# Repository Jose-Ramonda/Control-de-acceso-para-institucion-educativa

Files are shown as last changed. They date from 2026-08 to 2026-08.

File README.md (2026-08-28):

# Control de acceso para institución educativa
Repositorio del proyecto final de carrera "Control de acceso para institución educativa" de la Facultad de Ciencias Exactas Ingeniería y Agrimensura de la Universidad Nacional de Rosario. Desarrollado por José Ramonda y dirigido por Prof. Ing. Daniel Marquez.
La explicación detallada del desarrollo se encuentra en el informe subido.

El directorio "Servidor" contiene los archivos de implementación del servidor para funcionar en cualquier dispositivo con Linux. Para utilizar instalar Mosquitto y Node-Red, clonar el repositorio, copiar el backup de Node-Red (configurar seguridad de acceso). Luego crear entorno virtual y configurar los archivos "main.py" y "bot/bot.py" como servicios.
Configuraciones importantes: 
-Añadir archivo de texto plano con token de API de Telegram
-Configurar en "bot/botconfig.py" la ruta del archivo
-Para implementación en Raspberry Pi, activar uso de UART y cambiar la dirección del puerto serie. 
-Establezca sus propias credenciales de acceso al bot, así como su propio padrón de accesos.

El directorio "terminales" incluye los proyectos de ESP-IDF donde se programó el firmware de las placas de desarrollo ESP32 Devkit y ESP32-CAM, y los arcivos de Kicad de diseño de una PCB para el prototipado.

Para consultas comunicarse a josenramonda@gmail.com

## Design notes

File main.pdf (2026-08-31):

## Universidad Nacional de Rosario

## Facultad de Ciencias Exactas, Ingeniería y Agrimensura

## Escuela de Ingeniería Electrónica

## Proyecto II

## Control de Acceso para institución

## educativa

## Año: 2026

### Autor: Ramonda, José

Legajo: R-4423/7

Director:

### Prof. Ing. Daniel Marquez

### Rosario, 31 de agosto de 2026

## 1. Resumen

En el presente documento se desarrolla el proyecto de finalización de carrera “Control de acceso para institución educativa”, el cual implementa un sistema de gestión y registro de ingresos. El sistema permite el acceso regular del personal autorizado mediante credenciales basadas en tecnología NFC (Near Field Communication) y la validación remota de visitantes externos por parte de un operador humano, utilizando el reconocimiento visual a partir de fotografías recibidas en un dispositivo móvil.

## Índice

1. Resumen | 2
2. Problemática | 5
3. Funcionamiento del sistema | 6
4. Alcance del proyecto | 9
5. Terminales | 10
6. Servidor | 32

6.4. Selección del hardware del servidor y migración a Linux embebido . . 42
7. Seguridad | 43
8. Ensayos | 49
8.3.1. Medición de tiempo de apertura por acceso autorizado . . . . 50
9. Conclusiones | 54
10.Trabajo futuro | 55
11.Referencias | 56
12.Anexos | 57
12.2.3. Ensayo a 115200 baudios con retardo entre encuestas de 10 ms 67

## 2. Problemática

La problemática fue planteada por la dirección de la E.E.S.O. N.º 214 “Mariano Moreno”, ubicada en Santa Isabel, provincia de Santa Fe. Asumiendo el rol de cliente, la institución expuso la siguiente situación respecto al control de acceso y la seguridad: las puertas del establecimiento no pueden permanecer abiertas de forma ininterrumpida; sin embargo, resulta inviable destinar personal exclusivo para habilitar el ingreso de individuos autorizados o visitantes externos (como tutores legales) fuera de los horarios de entrada masiva. Frecuentemente, las oficinas de dirección se encuentran vacías y el personal asistente se halla realizando tareas de mantenimiento en zonas donde no es posible percibir el timbre sonoro. A esto se suma la ineficiencia que supone el desplazamiento físico con llaves mecánicas hacia cualquiera de los múltiples puntos de acceso cada vez que se requiere habilitar una entrada.
Para dar respuesta a estas necesidades, se requiere el diseño de un sistema que: Permita el acceso autónomo del personal de la escuela (docente y no docente), guardando los registros correspondientes para auditoría.
Permita que un operador autorizado habilite el acceso a un visitante externo de forma remota desde un dispositivo móvil, validando la identidad del individuo mediante una captura fotográfica.

Esta modalidad también permite gestionar los ingresos durante el horario de clases, momento en el cual las puertas deben permanecer bloqueadas, a diferencia de los horarios de entrada y salida regular. Por fuera del horario de actividades escolares, el edificio se asegura convencionalmente mediante cerraduras mecánicas.
Un condicionante crítico para el diseño es el factor económico, dado que los costos de implementación deben ajustarse estrictamente a las limitaciones presupuestarias de una escuela pública.
Respecto a las características arquitectónicas, el edificio ocupa una manzana completa y el sistema debe gestionar tres puntos físicos de acceso: la entrada de alumnos (patio principal), la entrada de docentes y el portón del bicicletero, el cual comunica con el patio exterior destinado a las clases de educación física. Las distancias de cableado desde cada una de estas puertas hasta la oficina designada para alojar el servidor central son de 7,5 m, 3 m y 40 m, respectivamente.

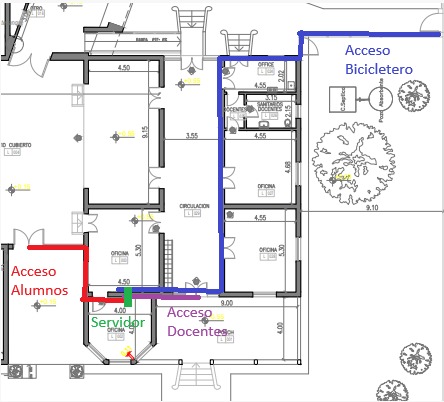
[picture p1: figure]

Figura 1: Plano de la institución resaltando los accesos y ubicación del servidor

## 3. Funcionamiento del sistema

El sistema funciona en un horario determinado correspondiente al horario escolar. Por fuera de ese horario el sistema permanece inactivo y las puertas cerradas con llave. Durante los horarios de ingreso, las puertas permanecen abiertas para evitar “cuellos de botella” por parte de los alumnos, pero una vez iniciado el periodo de clases, las puertas permanecen cerradas. Del lado de afuera se debe instalar un manijón que no permita que se accione el resbalón, ya que este lo acciona un destrabador eléctrico comandado por el sistema. Del lado interior se coloca un picaporte, que permita el egreso en todo momento por motivos de seguridad ante una posible evacuación. En casos de fallas del suministro energético, cuando el destrabador no pueda accionarse, basta con accionar el resbalón desde dentro con el picaporte o desde fuera con la llave.

En caso de que un visitante externo, por ejemplo el tutor de un alumno, visite la escuela, al tocar el pulsador del timbre de alguna de las puertas se le toma una fotografía que llega al dispositivo movil de la persona a cargo, quien decide si comandar o no una apertura. El timbre sonoro debe seguir funcionando normalmente.

El personal de la institución contará con credenciales de acceso en formato de tags NFC, con los que podrán acceder sin mediación humana. El sistema deberá llevar registro de cada acceso por cualquiera de los dos medios mencionados.

### 3.1. Arquitectura del sistema

El sistema se compone de un nodo servidor implementado en una single board computer (SBC) comunicado con tres nodos llamados terminales, construidos en base a microcontroladores, ubicados físicamente en cada punto de acceso. El servidor gestiona las comunicaciones, los registros, los permisos de acceso y por supuesto, comanda a los terminales. Los terminales son los que comandan, bajo demanda del servidor, el desbloqueo de las puertas mediante sendos relés que accionan los destrabadores eléctricos. También controlan las cámaras que toman las fotografías del exterior y los sensores NFC para transmitir la información de estos al servidor. Existen dos canales de comunicación entre nodos:

Comunicación serial cableada mediante protocolo RS-485 para el flujo de comandos, configuraciones y eventos, ya que es un estandar robusto utilizado en la industria, de velocidades considerables y pensado para grandes distancias.

Conexión a la red local, en el caso de los terminales via WiFi, mientras que el servidor puede conectarse via wifi o mediante cable de red si fuera posible, para transmitir las fotografías tomadas, dado que su transmición no es crítica en tiempo y que una fotografía se corresponde a un volumen de datos mayor que puede congestionar el canal principal.

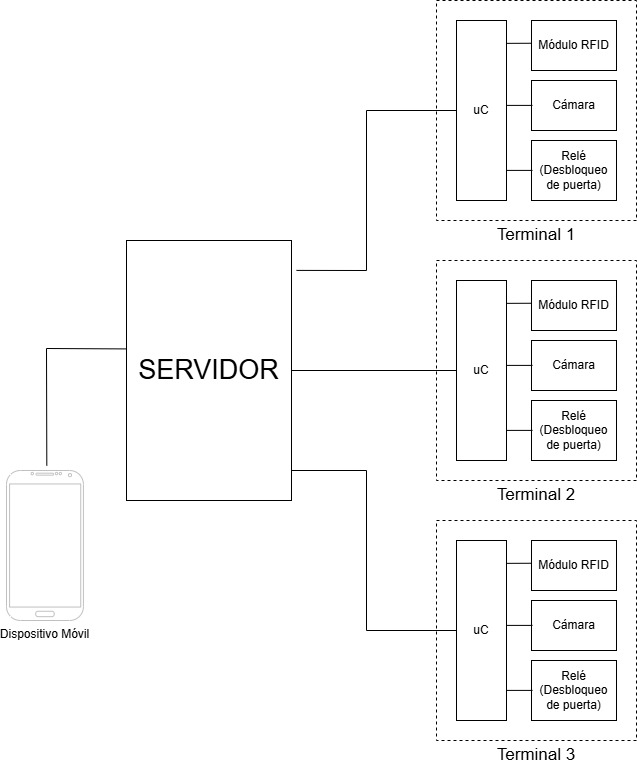
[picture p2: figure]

Figura 2: Diagrama de bloques del sistema

### 3.2. Actores del sistema

El sistema reconoce tres tipos de actores humanos.
Los accesos autorizados son aquellos que cuenten con una credencial o “tag” nfc autorizado y puedan acceder al presentarlo frente al lector. El lector debe validar la identidad del tag mediante contraseña, recolectar la identificación y contador de accesos y enviarla al servidor, para que este contraste con la lista de tags permitidos y responda con la orden de apertura o de no apertura. El Funcionamiento de la lectura y validación se detalla en la sección 5.2.6. El sistema debe tener capacidad para al menos 50 accesos autorizados, ya que representan al personal de la escuela (docente y no-docente) compuesto de alrededor de 30 personas. Se deja capacidad de reserva para cambios, incorporaciones y repuestos.
Los visitantes externos son aquellas personas que no tienen autorización de ingresar fuera del horario de apertura. Estos, al pulsar el boton del timbre, son fotografiados por la cámara del terminal. La fotografía es enviada hacia el servidor, el cual lo envía hacia el dispositivo móvil donde un usuario final valida la identidad del visitante y concede o no el acceso.
Los usuarios finales son aquellos con acceso a la interfaz de usuario de los dispositivos móviles. Para acceder a la interfaz estos deben iniciar sesión con credenciales (usuario y contraseña). Según las credenciales pueden tener distintos roles. El más básico es el de usuario, cuya sesión permanece abierta en el dispositivo a menos que se cierre explícitamente o que se reabra en otro dispositivo. Este rol permite solo acciones básicas tales como comandar aperturas o solicitar fotografías. Este rol está dedicado al personal no docente, directivo o administrativo. El sistema admite hasta 6 usuarios con este rol. Ciertos usuarios puden, mediante credenciales extra, abrir una sesión temporal de administrador, este rol permite configurar credenciales y añadir autorizaciones de accesos. Estas credenciales pertenecen solo a los directivos. Finalmente, queda un rol de desarrollador al cual se accede con otras credenciales mediante un comando no disponible en el menú. Este rol no está pensado para el personal de la institución sino a quienes esten a cargo de la instalación y el mantenimiento del sistema, y permite realizar acciones simples sobre este sin la necesidad de acceder al servidor mediante SSH.

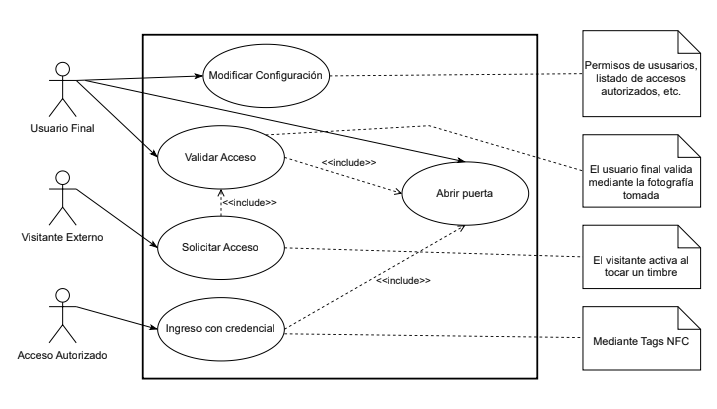
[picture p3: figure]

Figura 3: Diagrama UML de casos de uso.

### 3.3. Interfaces de usuario

La interfaz principal para los usuarios finales funciona a travéz de un bot de la aplicación de mensajería instantanea “Telegram”, ya que la API es amigable con los desarrolladores y permite utilizar menúes y comandos de forma sencilla, además de que soluciona la conectividad con el exterior, sin tener que configurar manualmente puertos ni firewalls. Otra ventaja respecto a desarrollar una aplicación nativa es que no hay que hacer un desarrollo distinto para cada sistema operativo móvil.
El bot es en esencia un programa que se ejecuta permanentemente en el servidor y mediante llamadas a API recibe, procesa y envía mensajes al chat del bot.
Los registros históricos de accesos se dan en formatos legibles y se cargan diariamente a google drive mediante su API. Esto permite un fácil acceso a los datos y un ahorro de memoria del servidor al almacenar en la nube.

### 3.4. Requerimientos del sistema

Los requisitos temporales del sistema no son estrictos al punto de requerir una respuesta en tiempo real; sin embargo, el uso de este debe percibirse fluido para los actores.
Se establece entonces que el tiempo dé respuesta para los accesos autorizados debe estar en el orden de los dos segundos, contando desde que el tag se presenta ante el sensor hasta que se acciona el relé que destraba la puerta.
En el caso del acceso de visitantes externos, el tiempo de respuesta se enmascara con la demora de la reacción humana, por lo que se establece una respuesta del orden de los cinco segundos del sistema para enviar la foto al usuario final, y del mismo orden para la apertura desde el comando manual, no pudendose controlar el tiempo de respuesta del usuario.
Otro requerimiento es la robustez frente a fallas del suministro energético y la conexión a internet. Para eso se propone conectar el servidor a una unidad UPS para mantenerlo activo ante cortes de energía, aunque sin funcionamiento. El sistema se habilita solo en un horario determinado, en caso de un desfazaje del reloj del servidor, por ejemplo por un reinicio sin conexión a internet para ponerse en hora, se puede mediante un tag especial forzar el funcionamiento del sistema fuera de horario, al menos hasta que se retome la conectividad y el sistema vuelva a funcionar con normalidad.
El último requerimiento crítico es el de seguridad del sistema, el cual se abarca en la sección 7.

## 4. Alcance del proyecto

El presente proyecto tiene como alcance el desarrollo de un prototipo funcional adaptable al entorno real descrito en la problemática, el cual contempla:

Construcción y programación de al menos un terminal, incluyendo el microcontrolador, la cámara, el módulo RFID y las comunicaciones con el servidor. Programación del servidor central, abarcando la administración de la comunicación multipunto, el procesamiento de datos de entrada, la historización de eventos relevantes y la integración con dispositivos móviles externos.

Implementación de los canales y protocolos de comunicación bidireccional entre los distintos nodos del sistema.
Configuración y programación de credenciales físicas (tags NFC) para la validación y prueba integral del sistema.

## 5. Terminales

Los terminales son los subsistemas expuestos al campo, cada uno representa un punto de acceso. A diferencia del servidor, que es único, el sistema se compone de varios terminales en cada punto de acceso, en este caso tres, pero en una aplicación similar el número de terminales podría extenderse. Por este motivo, los terminales fueron diseñados para ser fácilmente replicables, adaptables y de bajo costo, dado que el costo total del sistema aumenta marginalmente con cada nueva unidad incorporada.

### 5.1. Selección de hardware

Un terminal se compone de un microcontrolador, diversos módulos electrónicos y dispositivos de interfaz con el entorno físico. Entre ellos se encuentran:

Una cámara
Un sensor NFC
Un transceptor RS-485
Una antena WiFi
Dos relés, uno para permitir el ingreso destrabando la puerta y otro para hacer sonar el timbre
Un interruptor, para que los visitantes externos soliciten el acceso

La primera opción para utilizar como controlador principal del proyecto fue el kit de desarrollo ESP32-CAM, basado en el módulo WROOM-32, el cual integra un microcontrolador ESP32 junto con una antena de radio e interfaces para conectividades WiFi, Bluetooth, entre otras, con la particularidad de que incluye un zócalo (o socket) para conectar una cámara, por ejemplo la OV2640, la cual se vende junto con el kit. El mayor problema del módulo es la limitada cantidad de pines GPIO disponibles y utilizables, haciéndolo poco viable para ser el controlador principal del terminal, a pesar de ser computacionalmente capaz de cumplir con las funciones requeridas.
Se optó por una arquitectura distribuida, en la que el ESP32-CAM queda dedicado exclusivamente a la adquisición y transmisión de imágenes, mientras que el procesamiento principal y el control de los periféricos recaen sobre un segundo ESP32.

### 5.1.1. Microcontrolador

El ESP32 [1] fue seleccionado por ofrecer un adecuado equilibrio entre capacidad de procesamiento, memoria, periféricos integrados y costo, además de incorporar múltiples interfaces de comunicación (UART, SPI, I²C, WiFi y Bluetooth)[2]. Otra ventaja es su procesador de doble núcleo que permite simultaneidad real. Para el prototipo se utilizará un kit de desarrollo ESP32 DEV KIT V1, pudiéndose reemplazar en producción por el microcontrolador suelto, ya que esta etapa del sistema no requiere conectividad WiFi.

### 5.1.2. Cámara

Para el prototipo se optó, como ya se mencionó, al utilizar el kit de desarrollo ESP32-CAM, el cual se vende en conjunto con la cámara OV2640. Esta elección se basa en el fácil acceso y el bajo precio del módulo, el cual resuelve varios aspectos de la toma y transmisión de fotografías. La cámara cuenta con una resolución de 2 MP, suficiente para un reconocimiento de un rostro por parte de un validador humano. El módulo además incorpora un LED de alta luminosidad que funciona como flash de la cámara, y una memoria PSRAM externa de 4 MB que permite almacenar temporalmente las imágenes. La conectividad WiFi incorporada se utiliza para transmitir las imágenes al servidor mediante el protocolo HTTP.
Se comunica contra el microcontrolador principal mediante UART para recibir comandos y compartir información.

### 5.1.3. Comunicación RS-485

Para la comunicación con el servidor, el ESP32 debe comunicarse con un transceptor que “traduzca” UART a 485. Se seleccionó un módulo basado en el circuito integrado MAX485, ampliamente utilizado para la conversión entre UART y RS-485.

### 5.1.4. Lector NFC

Para la lectura y escritura de las credenciales se seleccionó un módulo basado en el circuito integrado PN532 de NXP. Este dispositivo implementa internamente los protocolos necesarios para la comunicación con etiquetas RFID/NFC de alta frecuencia compatibles, proporcionando una interfaz de programación de alto nivel que simplifica el desarrollo del firmware. Asimismo, ofrece soporte para operaciones de lectura, escritura y autenticación sobre las etiquetas empleadas en el sistema. Para este desarrollo se optó por las etiquetas NTAG-21X [3]como credenciales de acceso.
El módulo cuenta con interfaz SPI para comunicarse con el controlador principal.

### 5.1.5. Interfaces de campo

Para la activación del timbre y el desbloqueo de la puerta se incorporan sendos relés en cada terminal, comandados por salidas digitales del controlador. Ambos equipos operan con tensión de red de 220 V CA. Para el pulsador del timbre, se conectó entre GND y la entrada digital del ESP32 una bornera, que permita aprovechar el pulsador ya existente en la instalación.

### 5.1.6. Alimentación

Los ESP32 operan a 3,3 V, pero pueden alimentarse con 5 V, ya que las placas cuentan con reguladores de voltaje LDO incorporadas. El PN532 también cuenta con un regulador y tanto el transceptor como los relés se deben alimentar con 5 V. Se propone entonces alimentar mediante un conector micro USB tipo A (u opcionalmente un tipo C), para poder alimentar el circuito desde una fuente externa, como por ejemplo un cargador de teléfono celular. Se añade además un capacitor de 470 µF para mitigar los picos de consumo de corriente que se producen durante el encendido de la cámara o de la interfaz WiFi.

### 5.1.7. Diseño de circuito impreso

Para simplificar el conexionado y dotar de robustez mecánica al prototipo, se diseñó mediante el entorno KiCad el esquemático del circuito y su correspondiente placa de circuito impreso o PCB (Printed Circuit Board). El esquemático base puede observarse en el Anexo 12.1. En este se incluye, para cada microcontrolador, un par de pines asociados a GND y al terminal TX de la interfaz UART0, permitiendo conectar un adaptador serie-USB para monitorizar la consola de depuración y analizar los registros (logs) del sistema.

Dado que la placa se fabricó a simple faz (una sola capa de cobre) y el ruteo no permitía resolver todos los cruces de pistas en el plano, se generó una variante del esquemático documentada en el mismo anexo, donde se incorporan terminales y resistencias de 0 Ω que actúan como puentes (jumpers) de interconexión.

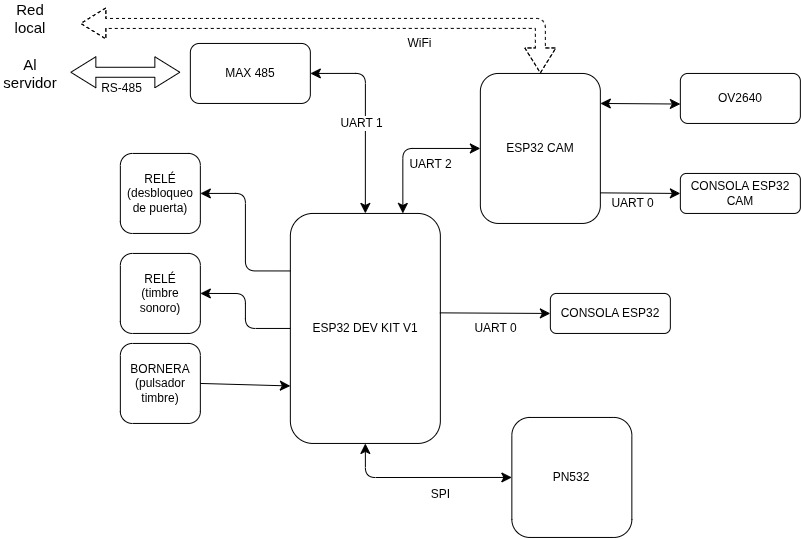
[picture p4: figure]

Figura 4: Diagrama de bloques de interfaces de cada terminal.

La PCB fue fabricada con el router CNC disponible en el espacio maker de la FCEIA.

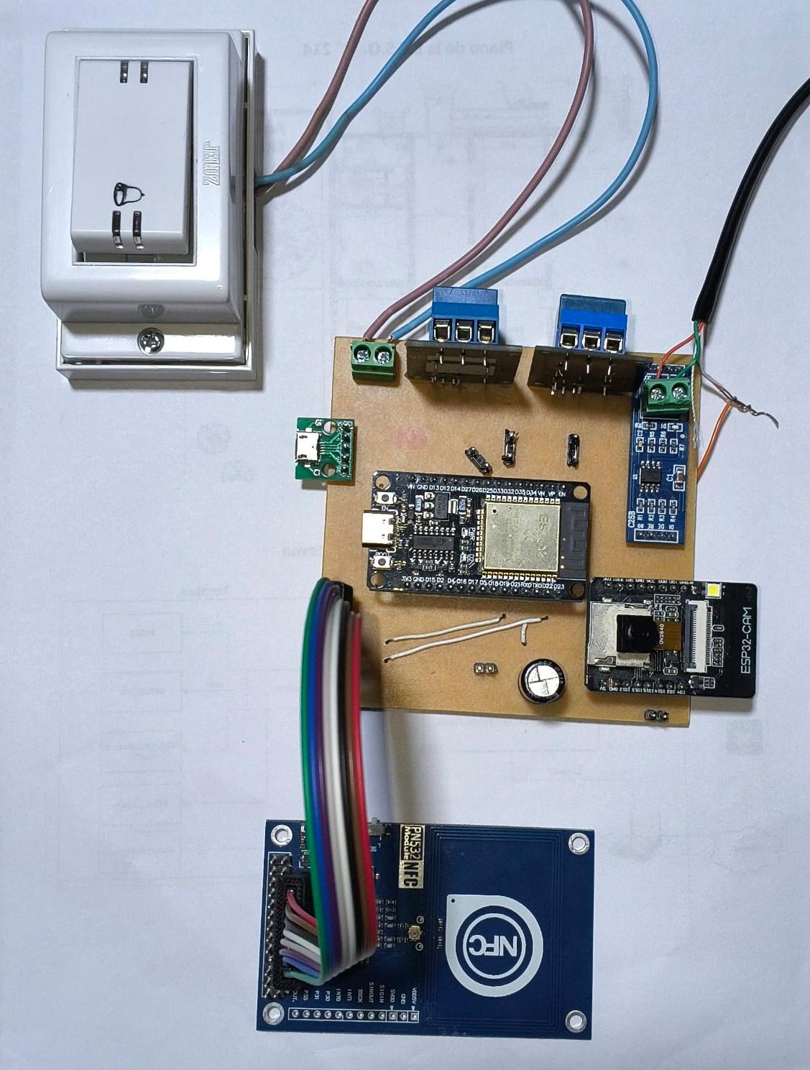
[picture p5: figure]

Figura 5: Montaje en PCB del prototipo.

### 5.2. Firmware del controlador

Para programar el firmware del controlador, se utilizó el framework oficial de Espressif, ESP-IDF [4] [5], a través de la extensión del entorno Visual Studio Code. Dado que el controlador debe ejecutar de forma concurrente tareas de comunicación, adquisición de datos, procesamiento y control de dispositivos externos, se optó por desarrollar el firmware utilizando el sistema operativo de tiempo real FreeRTOS, el cual se incorpora en forma nativa en el SDK de ESP32, por lo que la integración es orgánica.

### 5.2.1. Sistemas operativos en tiempo real

Una aplicación bare-metal suele organizarse alrededor de un lazo principal (superloop) que ejecuta secuencialmente todas las funciones del sistema. En cambio, un RTOS permite dividir la aplicación en múltiples tareas concurrentes, administradas por un planificador que decide cuál debe ejecutarse en cada instante. En FreeRTOS [6][7] [8] una tarea corresponde a una función independiente, normalmente implementada como un bucle infinito, aunque puede finalizar cuando su ejecución concluye. La ejecución de las tareas se alternan orquestadas por el scheduler o planificador. Esta arquitectura permite modularizar el código, asignar prioridades y encapsular las responsabilidades.

Otra funcionalidad de los RTOS es, como su nombre lo indica, la posibilidad de asegurar la ejecución de ciertos ciclos con limitaciones de tiempo real, aunque en esta aplicación los requisitos temporales no son estrictos.
Las tareas pueden encontrarse en cuatro distintos estados:

Running o corriendo, la tarea se está ejecutando.

Ready o lista, la tarea está lista para ejecutarse, pero la CPU está tomada por otra tarea de mayor o igual prioridad.

Suspended o suspendida, la tarea se encuentra “dormida”, es decir temporalmente desactivada, solo puede ser reactivada por otra tarea.

Blocked o bloqueada, la tarea está esperando a un evento para estar lista.

Solo las tareas en estado Running consumen ciclos de CPU, por lo que se dice que los demás estados componen un “superestado” llamado Not Running.
Para definir cuál tarea de todas las que están listas se ejecuta hay dos formas de trabajar, la operación colaborativa, donde cada tarea cede el procesador en determinado momento, y la operación apropiativa, donde el scheduler interrumpe una tarea para darle CPU a otra. FreeRTOS para ESP-IDF utiliza planificación apropiativa basada en prioridades.
La apropiación puede ser para ejecutar una tarea de mayor prioridad o bien para alternar entre varias tareas de igual prioridad.
La suspensión se da cuando una tarea debe dejar de ejecutarse temporalmente, una tarea puede suspenderse a sí misma y a otras, pero solo puede ser retomada desde otra tarea.
El bloqueo se da cuando una tarea debe esperar un evento para continuar su ejecución, tal como la finalización de un timer, el cambio de una bandera o bien el aviso de otra tarea. La espera de una interrupción no puede bloquear directamente a una tarea, pero puede enviarse el aviso de desbloqueo desde el callback de dicha interrupción.
Las tareas interactúan entre sí mediante herramientas de comunicación y de sincronismo.
Las principales herramientas de sincronismo son los semáforos. Un semáforo contiene un contador. “Ceder” o “dar” un semáforo aumenta el contador y tomarlo lo disminuye, si se intenta tomar un semáforo que está en cero, la tarea se bloquea. Un caso particular es el semáforo binario, el cual solo puede aumentar hasta uno, es decir, reconoce dos estados. Es particularmente útil para desbloquear una tarea desde otra de forma genérica.
Un caso particular del semáforo binario es el semáforo de exclusión mutua o “mutex”, el cual solo puede ser retornado por la misma tarea que lo tomó, se utiliza para proteger espacios de memoria de una escritura por parte de otra tarea, pudiendo dejar los datos compartidos en un estado inconsistente.
Otro método de sincronismo es la notificación, la cual es más rápida y eficiente que el semáforo binario, pero sirve solo para notificar una tarea en específico.
Las estructuras de comunicación tienen como funcionalidad principal enviar datos de una tarea a la otra, aunque también pueden utilizarse para la sincronización. Ejemplos de estas estructuras son el stream buffer, el cual transmite cadenas de bytes enteros de longitud variable, ideal para flujo continuo de datos, el message

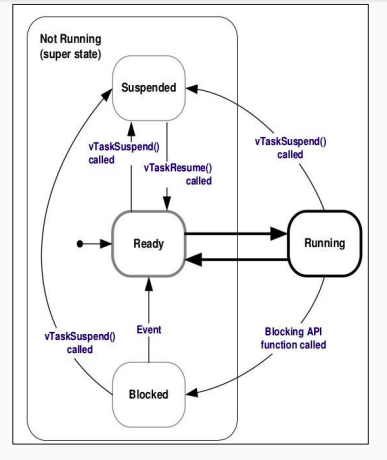
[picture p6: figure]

Figura 6: Diagrama de estados de una tarea en un RTOS.

buffer, el cual envía mensajes de bytes enteros de longitud definida, mejor para datos ya filtrados, y la queue o cola de mensajes, la cual puede transmitir elementos de tamaño definido, por ejemplo estructuras de datos.

### 5.2.2. Comunicación con el servidor

Para comunicar el controlador con el servidor se seleccionó, en la capa física del modelo OSI el protocolo serial RS-485 como ya se indicó. El transceptor “traduce” las señales diferenciales al protocolo UART por el cual se comunica el microcontrolador. Para el microcontrolador se desarrollaron dos librerías que gestionen la comunicación. La primera, llamada app_uart se ubica en la capa de enlace de datos y se ocupa de gestionar la recepción y el envío de tramas crudas, sin ningún tipo de procesamiento. La segunda, llamada protocol, se ubica en la capa de aplicación y le corresponde procesar las tramas entrantes así como preparar las salientes.
Los datos entrantes son recibidos en una tarea dedicada de la librería app_uart y cargados en un stream buffer, el cual debe ser leído por la tarea correspondiente de la librería del protocolo.

La librería app_uart se compone de tres funciones y una tarea:

1 | void uart_init ( void ) ;
2 | void uart_rx_task ( void * pvParameters ) ;

3
4 | void app_uart_send ( uint8_t * trama , int len ) ;
5 | StreamBufferHandle_t uart_get_rx_streambuffer ( void ) ;

La función de inicialización primero crea el stream buffer, el cual es local, por lo que para recuperar los datos se debe acceder a él mediante un “getter”, es decir una función pública que devuelve la estructura de datos.
Luego se configura la operación del periférico, basado en las guías de la documentación oficial y códigos de ejemplo, y luego adaptado a las necesidades de este proyecto. Se crea una estructura de configuración donde se definen los parámetros de operación, se elimina el bit de paridad y el control de flujo por hardware, ya que el método de detección de errores se aplica en la capa de aplicación y el flujo se programa a mano. La inicialización configura el puerto UART1 para trabajar en modo RS-485 y reaccionando a eventos mediante interrupciones, todo esto de forma transparente al desarrollador.
Lo siguiente es instalar el driver, en este caso se definen los tamaños de los buffers de recepción y de transmisión (este último en 0). Estos buffers son “invisibles” para el programador, por ejemplo el buffer de recepción es circular y se va llenando con los bytes entrantes y vaciando con los que se leen explícitamente, el tamaño sirve para ver cuánto se pueden acumular. Se configuró en 2048 para asegurar el funcionamiento de forma conservadora, lo que se corresponde con más de 100 tramas de longitud máxima según se define en el protocolo. El driver también se le carga una cola de eventos junto con su tamaño. Esto configura a la UART para trabajar por interrupciones que se ejecutan de forma transparente al usuario, cada vez que llegan datos, el sistema operativo interrumpe y carga en la cola un evento de bytes entrantes.
Posteriormente, se cargan las configuraciones de la estructura, y se asignan los pines que se utilizaran. Finalmente, se establece el modo de trabajo, en este caso RS-485, que configura el pin antes definido como RTS para comandar el transceptor según la dirección de los datos. El pin restante es para control de flujo por hardware por lo que se deja sin usar.
La tarea uart_rx_task reacciona a los eventos y ante un evento del tipo UART_DATA, pone los datos en un Stream Buffer static del archivo. Esto lo hace leyendo la cola de eventos.
La cola bloquea la tarea hasta la ocurrencia de un evento, en el caso de que el evento sea de datos se leen y se guardan en el buffer. Hay más tipos de eventos relativos a posibles fallos, como un desborde del buffer de recepción o bien problemas al recibir los datos. Se implementaron logs para estos casos sin desarrollar. Quedan como mejora futura el tratamiento de estos eventos cuando se acote el buffer de recepción y se suba la velocidad.
Para enviar los datos por UART se creó la función app_uart_send, a la cual se le pasa como parámetro un puntero a un buffer (arreglo de enteros sin signo de 8 bits) y un campo de longitud.
La elección de esta arquitectura se debe a que la implementación del protocolo requiere que los datos entrantes se entreguen en un streambuffer y los salientes se reciban mediante un puntero. Manteniendo estas estructuras se podrían desarrollar librerías para que el protocolo opere con diferentes capas físicas, como por ejemplo CAN bus.

### 5.2.3. Protocolo Ramodbus

La implementación de este módulo conllevó un doble desafío, primero la definición de un protocolo de capa de aplicación y segundo la implantación de este como librería, manteniendo robustez, desacoplamiento y portabilidad. Se decidió llamarlo “Ramodbus” por la inspiración a Modbus y el apellido del desarrollador.
Se evaluó utilizar Modbus RTU, dado que es un protocolo robusto, altamente probado y muy documentado con librerías en múltiples plataformas, además de estar diseñado para trabajar sobre RS-485.
La desventaja radica en que, al ser un protocolo orientado a comunicaciones con PLCs, su uso en una aplicación IoT requiere adaptaciones sustanciales para integrar comandos y tipos de datos diferentes. Se decidió entonces desarrollar un protocolo propietario inspirado en Modbus RTU pero adaptado a las necesidades de este proyecto, con la flexibilidad suficiente para ser reutilizado en aplicaciones similares.
De Modbus RTU se mantienen las siguientes características:

Comunicación maestro - esclavo multipunto con múltiples esclavos

Arbitraje mediante polling

Funcionamiento en base a comandos

Verificación de errores mediante CRC de 16 bits

La primera diferenciación viene de la complejidad de implementar un sincronismo temporal como Modbus RTU, en lugar de manejar los inicios y finales de trama mediante silencios y timeouts, se decidió incluir un byte de inicio de trama y un campo de longitud en el encabezado. De esta forma la trama queda de la siguiente manera:

START | NODO_ID | CMD | LEN | PAYLOAD | CRC16
0xAA | 0x0A | 0x00 | 0x00 | long variable | 0x85 0x8C

La principal innovación viene de los comandos, esta idea surgió en la etapa de implementación como método para optimizar la memoria reservada. Como Modbus RTU es orientado a registros, tiene pocos comandos, pero siempre mantiene un payload mínimo, ya que requiere por ejemplo para encender una salida, la dirección de esta.
En una aplicación IoT se pueden tener funcionalidades muy simples que requieran solo de una orden, como por ejemplo encender el relé que desbloquea la puerta en este proyecto. Se decidió entonces que Ramodbus tenga tantos comandos como sea necesario para cada aplicación específica.
Esto determina en principio dos tipos de comandos: los obligatorios del protocolo y los comandos de la aplicación. Existen tres comandos obligatorios.

El comando 0x00 que del lado del maestro es un polling, una encuesta que pregunta al esclavo si hubo algún evento. En el caso de que el maestro requiera enviar un comando, simplemente reemplaza el comando de polling por el del comando. Desde el esclavo un comando 0x00 es un acknowledge (ACK).
El comportamiento del esclavo es responder de inmediato con los datos que tenga listos, si el maestro le pide datos, el esclavo probablemente responda con un ACK de inmediato y entregará los datos como respuesta a un ciclo de polling posterior. Esto puede parecer en principio una debilidad, porque se debe configurar el maestro para esperar las respuestas y confirmaciones por varios ciclos hasta considerar reenviar la solicitud. Sin embargo, esto trae una potencial mejora para aplicaciones críticas en tiempo con mayor número de esclavos, ya que al ofrecer una respuesta inmediata, se puede acelerar el ciclo de encuestas, incluso aprovechando el determinismo del RTOS. Esto es uno de los dos factores que tienen el potencial de compensar la diferencia de longitud en las tramas.
El segundo comando obligatorio es el 0x01, solo de parte del esclavo y representa el not-acknowledge (NACK), se dispara el CRC se valida mal o si el campo len tiene un valor fuera de rango. Quedan a futuro posibilidades de agregarle más validaciones. El tercer comando obligatorio es el 0x02, el cual desde el lado del maestro es una orden de reset por software, mientras que desde el lado del esclavo es una confirmación de inicialización exitosa.
Los comandos también se dividen en Control commands (comandos de control) y Stream commands (comandos de flujo). Los comandos de control son aquellos con índices (decimales) entre el 0 y el 99 y no llevan payload y se usan para disparar eventos de forma directa. La versatilidad del protocolo es que uno define el significado desde el comando 0x03 en adelante, como analogía a Modbus debería tomarse, por ejemplo, un número distinto para encender cada bobina. Esto es el segundo factor que compensa la longitud del encabezado, ya que permite en muchos casos prescindir de payload y enviar tramas más breves. Al enviar un comando de control el campo len se pone en 0. Los comandos de flujo son los numerados decimalmente entre el 100 y el 255 y son todos aquellos que requieran de un payload. Estos permite ,si se quiere replicar algo más similar a Modbus RTU se pueda diseñar la tarea para que lea a qué salida atacar en el payload, pero el uso pensado es el intercambio de datos. Se sugiere que los comandos de la aplicación tengan correspondencia entre maestro y esclavo. Por ejemplo si un comando desde el lado del maestro es encender una salida, se utilice el mismo desde el lado del esclavo como confirmación.
De la misma manera si los comandos fueran de diferente tipo, por ejemplo el maestro envía una solicitud de datos (control) y el esclavo devuelve los datos (flujo), se pueden usar dos comandos diferentes o bien utilizar en ambas direcciones el mismo stream command, esto es más prolijo, pero por cuestiones de implementación debe incluirse una trama “dummy” en el payload de la orden.
La cantidad de comandos de cada tipo (incluyendo los obligatorios) son un parámetro de inicialización del protocolo. Debido a la implementación, el protocolo especifica que la numeración de los comandos debe ser consecutiva, es decir si se va a usar 10 comandos de flujo, se debe inicializar el protocolo con 10 stream commands y definirlos del 100 al 110. Si se quiere usar un comando 130, pero no los del medio, se inicializa con 30 stream commands, con el costo de memoria que esto conlleva. El protocolo se implementa en una librería propia, cuyo archivo de cabecera define algunas macros de uso interno pero accesibles tales como el byte de start, la longitud del encabezado y los índices de comando obligatorios. También define varias estructuras tanto de uso interno como de uso público vía API.
El protocolo se ejecuta mediante dos tareas: el parser, el cual recibe los datos, los valida y los pasa a la tarea correspondiente a cada comando, y el dispatcher el cual se ocupa de gestionar la transmisión de datos. Ambas funciones son privadas y las tareas se crean mediante la función de inicialización protocol_init, la cual lleva como argumento un puntero a un tipo de dato de configuración:
1 | typedef struct {
2 | | int ctrl_cmds ;
3 | | int st_cmds ;
4 | | uint8_t masterid ;
5 | | uint8_t nodoid ;

6
7 | | int parser_stack ;
8 | | parser_interface_func buffer_getter ;
9 | | int parser_priority ;

10
11 | | int dispatcher_stack ;
12 | | dispatcher_interface_func sender ;
13 | | int dispatcher_priority ;

14
15 | } | protocol_params_t ;

Los primeros campos son las cantidades de comandos de cada tipo, luego le siguen las id del nodo propio y el maestro. Le siguen algunos de los parámetros de configuración de las tareas para que el usuario de la api pueda definir en cada una el stack y la prioridad. Buffer_getter y sender son datos del tipo

1 | typedef void (* dispatcher_interface_func ) ( uint8_t * , int) ;
2 | typedef StreamBufferHandle_t (* parser_interface_func ) ( void )
| | ;

Que son punteros a funciones, hacen de interface y se les pasa en el main las funciones de la API de app_uart, esto para mantener las funciones compatibles con otros protocolos.
El protocolo es reactivo, para gestionar la comunicación y el sincronismo entre el parser y las tareas que reaccionen a cada comando se parte desde la premisa de que a cada comando que recibe el esclavo le corresponde una tarea de forma unívoca. La idea original sin diferenciar comandos proponía unificar sincronismo y comunicación mediante message buffers. La ventaja que ofrecen las funciones de FreeRTOS es que la función de recepción puede bloquear una tarea en ausencia de datos. Se propuso crear un arreglo de estos, de forma tal que el índice del arreglo se corresponda con el número de comando, de aquí surge la necesidad de definir los comandos de forma contigua. Esto permite transmitir solo los datos sin ninguna información extra, ya que el comando define que tarea lo recibe.
El uso únicamente de buffers de mensaje tiene dos grandes problemas y ambos nacen del hecho de tener comandos que no transportan datos: El primero es que, al tener que definir el arreglo con buffers de igual tamaño, se desperdicia memoria. El segundo es que al no haber payload, los buffers de recepción nunca despertarían a la tarea, por lo que habría que enviar siempre un byte “dummy”.
Frente a esto surge la idea de separar los comandos, aquellos que transporten datos se llamaron comandos de flujo y mantuvieron la arquitectura, desfasando en 100 unidades los índices. Los comandos cortos, los de control, se sincronizan con sus respectivas tareas usandose de forma análoga a sus contrapartes como índices de un arreglo de semáforos binarios. El parser libera el semáforo correspondiente desbloqueando la tarea, que debe luego tomar el semáforo para volver a bloquearse al cumplir su función.

Como no se puede crear un arreglo estático dentro de una función, ambos arreglos se crean como punteros estáticos en el archivo de implementación.

1 | static MessageBufferHandle_t * cmd_buff = NULL ;
2 | static SemaphoreHandle_t * cmd_smph = NULL ;

Posteriormente, la función de inicialización luego de llenar los valores estáticos de las id, y validar las cantidades de comandos, crea ambos arreglos.

Como los objetos se deben crear con funciones específicas, primero se reserva la memoria mediante malloc y luego mediante un bucle for se crea cada buffer y cada semáforo.

Luego, cada tarea, mediante una función getter pública, recupera según corresponda el buffer de mensaje o el semáforo binario correspondiente.

La tarea parser mediante la función asignada como parámetro utiliza un stream buffer para despertar e ir pre procesando los datos. También hay un buffer temporal donde se van guardando los datos válidos entrantes, y se va sobreescribiendo en las iteraciones

El funcionamiento es mediante una máquina de estados finita, la cual comienza en un estado de espera con la tarea bloqueada. Al recibir un dato la tarea despierta y se compara hasta coincidir con el byte de inicio de trama. En ese caso evoluciona a un estado de validación de id. En caso de que la id sea la de otro nodo, el dato se descarta y se vuelve a la espera, en el caso de que el mensaje sea para ese nodo, se guarda el dato en el buffer y se evoluciona a un estado que lee y guarda el campo de comando y el campo de longitud. Si la longitud del payload es mayor a 0 se pasa a un estado intermedio que guarda el payload, y en ambos casos se termina en un estado de validación del CRC. Si el CRC es válido se pasa a un estado de parseo donde se libera el semáforo o bien se envía el payload por el buffer correspondiente, para luego mediante una notificación de tarea avisar al dispatcher que envíe una respuesta. Si el CRC no es válido se pasa a un estado de rechazo donde se notifica a la tarea de dispatcher que envíe un NACK.

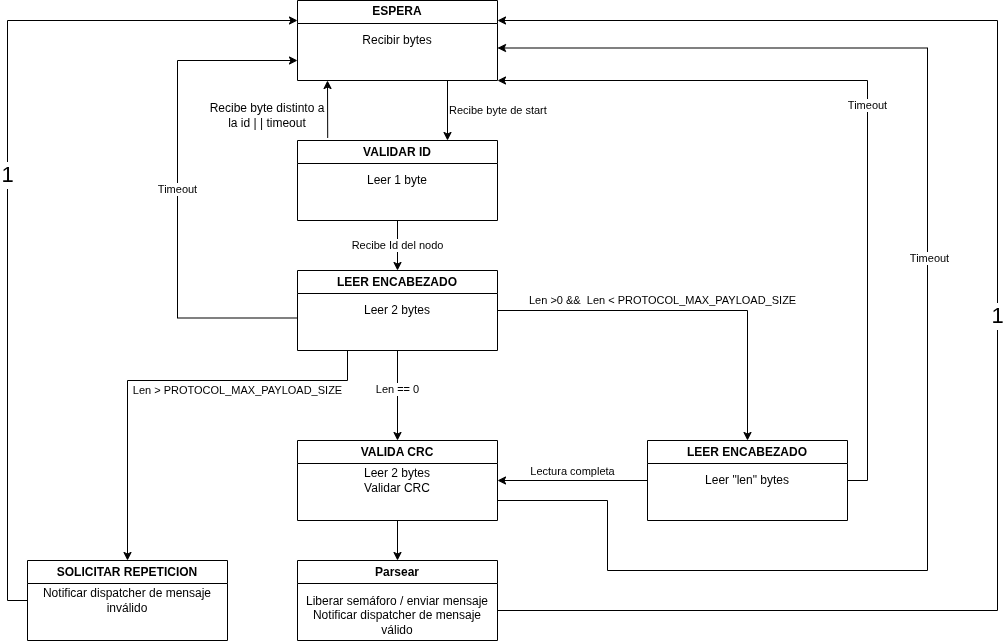
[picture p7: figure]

Figura 7: Máquina de estados finitos del parser del protocolo.

Cuando una tarea de algún módulo quiere mandar un dato debe utilizar la función composer. Esta recibe como argumentos el comando a enviar, la longitud del payload y un puntero a un buffer para los datos. Esto para no pasar la trama por copia, haciendo el transporte más eficiente. Esto conlleva un riesgo por lo que se añade como argumento un semáforo que bloquee la escritura de este.
Para la comunicación entre el composer y el dispatcher se utiliza una cola de mensajes, ideal para transmitir estructuras como las creadas para el protocolo:

typedef struct {

uint8_t id ;
uint8_t cmd ;
uint8_t len ;
uint8_t * payload ;
uint16_t CRC ;
} msj_t ;

typedef struct {

msj_t msj ;
SemaphoreHandle_t semaforo ; } q_msj_t ;

La estructura de cola q_msj_t contiene al semáforo y a una variable de la estructura msj_t. La función calcula el CRC en base a los datos recibidos y llena la estructura para encolarla. Previamente, si se utilizó un semáforo, lo toma para proteger al buffer de ser modificado durante la transmisión.
La tarea dispatcher es la encargada de llamar a la función (en este caso app_ uart_send) que transmite los mensajes. Esta guarda el mensaje en un buffer y lo envía mediante la función descripta anteriormente

La tarea se mantiene bloqueada hasta recibir una notificación del parser, es decir solo transmite en respuesta a las encuestas. En el caso de que la notificación sea de fallo transmite un comando de NACK. En el caso de que la notificación sea de aviso de mensaje válido, va a revisar si en la cola del composer hay datos en espera que transmitir, para armar el mensaje y enviarlo. Luego de enviarlo libera el semáforo para permitir la reescritura del buffer de datos. En caso de que no haya datos en cola, construye y envía un comando de ACK.
Este comportamiento revela dos características importantes del protocolo: Primero que, dada la alta prioridad que deben tener las tareas de este respecto a las demás de la aplicación para mantener la fluidez, lo más probable es que la respuesta a cualquier comando siempre sea un ACK y que los datos esperados se transmitan en un ciclo de polling siguiente.
Lo siguiente es que los datos se transmiten en orden de llegada, este orden vendrá dado en la aplicación por la prioridad que se le asigne a cada tarea.

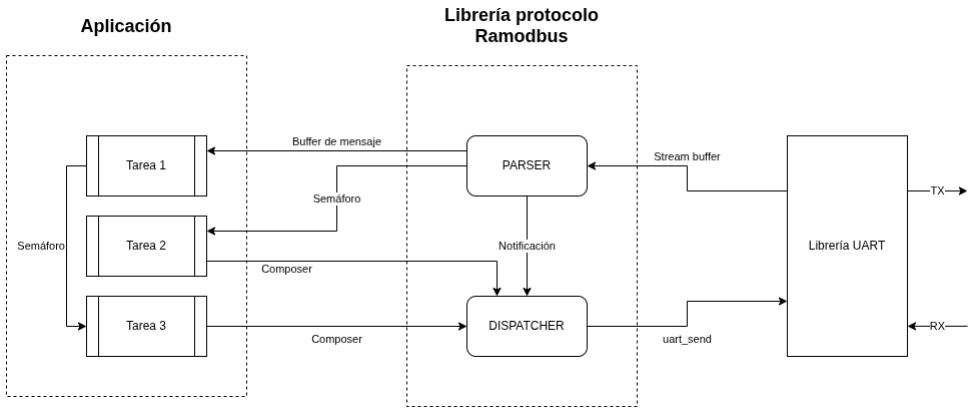
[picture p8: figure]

Figura 8: Esquema de operación del protocolo.

Si bien a cada comando (exceptuando los dos primeros) se le corresponde una tarea, esto no necesariamente se cumple en el sentido inverso. No todas las tareas tienen que devolver confirmaciones. Además, puede que haya tareas que encolen datos, pero que reaccionen no a un comando de un protocolo sino a cualquier otro evento, como una interrupción o la orden de otra tarea.

### 5.2.4. Tareas reactivas al protocolo

La estructura de una tarea que reacciona a un comando del protocolo es, en principio, sencilla. Durante la inicialización obtiene, mediante la función getter correspondiente, el semáforo binario o message buffer asociado al comando y verifica que la operación haya sido exitosa. Luego entra en un bucle infinito en el que permanece bloqueada indefinidamente hasta recibir un mensaje o liberarse el semáforo. Una vez desbloqueada, ejecuta la acción correspondiente y vuelve al estado bloqueado al finalizar. Como ejemplo, la tarea que implementa el comando obligatorio de reinicio se muestra a continuación.

1 | void reset_task ( void * pvParameters ) {

2
3 | SemaphoreHandle_t cmd_sem = protocol_get_ctrl_sem ( CMD_RESET ) ;
4 | if ( cmd_sem == NULL ) {
5 | ESP_LOGE (" RESET ", "No␣se␣ pudo ␣ obtener ␣el␣ semaforo ␣de␣ reset "
) ;
6 | esp_restart () ;
7 | }

8
9 | while (1) {
10 | if ( xSemaphoreTake ( cmd_sem , portMAX_DELAY ) == pdTRUE ) {
11 | esp_restart () ;
12 | }
13 | }
14 | }

### 5.2.5. Manejo de entradas y salidas digitales

Este módulo implementa el control de las dos salidas digitales del controlador, correspondientes al relé de apertura de la puerta y al relé del timbre, además de la lectura de la entrada digital asociada al pulsador del timbre.
Durante la inicialización se configuran los pines de entrada y salida, se obtienen mediante la API del protocolo los semáforos correspondientes a los comandos de apertura de puerta y captura de fotografía, y se crea un temporizador de software utilizado para controlar la duración del accionamiento del relé del timbre.
La apertura de la puerta se implementa mediante una tarea reactiva al protocolo. Esta permanece bloqueada sobre el semáforo asociado al comando correspondiente y, al recibir la orden, activa el relé durante un tiempo configurable. Antes de volver al estado de espera envía la confirmación de ejecución mediante el protocolo de comunicaciones.
La detección de la pulsación del timbre se realiza mediante una interrupción externa configurada sobre el flanco descendente de la señal. Cuando esta ocurre, el manejador de interrupción libera el semáforo asociado a la captura de fotografías para despertar la tarea correspondiente y activa el relé del timbre. Como las rutinas de interrupción deben ejecutarse en el menor tiempo posible, la desactivación del relé no se realiza desde la propia interrupción sino mediante un temporizador de software, cuyo callback se ejecuta una vez transcurrido el tiempo programado. Esta arquitectura permite minimizar el tiempo de ejecución de la rutina de interrupción, delegando el procesamiento de mayor duración a las tareas del sistema operativo y a los mecanismos de temporización provistos por FreeRTOS.

### 5.2.6. Módulo de Identificación NFC

Para la lectura de credenciales de acceso, se utilizó un módulo basado en el chip PN532. La elección de este integrado radica en su amplia compatibilidad con protocolos RFID a 13,56 MHz, en particular la norma ISO/IEC 14443A, lo cual permite interactuar fluidamente con etiquetas de la familia NTAG21x (NTAG213, NTAG215 y NTAG216).
El control del chip se resolvió integrando el componente de software libre “garag__esp-idf-pn532”[9]. Esta biblioteca abstrae la comunicación SPI de bajo nivel y proporciona una API para la inicialización del controlador, la configuración de sus temporizadores y el envío de comandos al circuito integrado PN532.
El funcionamiento del módulo está gestionado por el RTOS mediante la creación de tres tareas concurrentes: Lectora, Programadora y Árbitro.
El sistema opera bajo dos estados mutuamente excluyentes: Modo Lectura y Modo Programación. Dado que ambas tareas (nfc_task y nfc_config_task) compiten por el uso del mismo periférico SPI y el mismo handler del PN532, se implementó un mecanismo de exclusión donde una tarea suspende a la otra (vTaskSuspend y vTaskResume) según el estado dictaminado por la tarea de arbitraje.
El árbitro, a su vez, reacciona directamente a las peticiones del coordinador central. Utiliza un semáforo binario cedido por maestro para alternar el estado. Si se recibe el comando de programación (CMD_PROGMODE), el sistema entra en una ventana de tiempo limitada (timeout) para configurar una nueva etiqueta. Si no se detecta actividad o finaliza el tiempo, el sistema retorna de forma segura a su estado natural de lectura, garantizando la operatividad ininterrumpida del control de acceso.
Uno de los mayores desafíos en sistemas de identificación por radiofrecuencia es la mitigación de ataques de clonación y repetición. Para abordar esto, el sistema no se limita a leer el UID (Identificador Único) de 7 bytes de la tarjeta, sino que implementa un esquema de autenticación dinámica y contadores de lectura, aprovechando el contador ya incorporado en el firmware de los tags.
Durante el modo de programación, al detectar una tarjeta NTAG virgen, el sistema ejecuta una función de derivación de claves utilizando HMAC-SHA256 (mediante la librería mbedtls). Se utiliza una clave maestra residente en el firmware del equipo y el UID único de la tarjeta para generar un hash de 32 bytes. Los primeros 6 bytes de este hash se truncan y se inyectan en la memoria de la NTAG para configurar el Password (PWD) de 4 bytes y el Password Acknowledge (PACK) de 2 bytes.
De esta forma, cada credencial del sistema posee una contraseña única matemáticamente vinculada a su hardware que se calcula en el acto, evitando la vulnerabilidad de alojar contraseñas en una base de datos.
El funcionamiento del sistema anti clonación se detalla en la sección 7 Adicionalmente, se configuran los registros de control de la NTAG para activar la función ASCII Mirror. Esta característica escribe automáticamente el valor actual del contador de interacciones interno de la etiqueta en la memoria de usuario cada vez que la tarjeta es leída. Se le llama espejado ASCII, ya que el valor del contador, alojado internamente en 3 bytes, se escribe en formato ASCII, es decir que el número que se guarda es el valor ASCII del caracter con el que se leería el número en formato hexadecimal, ocupando el doble de espacio. Por ejemplo el byte 0x2F (47 en decimal) se guardaría como 50 70, es decir los valores del caracter “2” y el caracter “F”. 12.3
Página (Hex) | Byte 0 Byte 1 | Byte 2 | Byte 3
0x29/0x83/0xE3 | MIRROR | RFUI | MIRROR_PAGE | AUTH0
0x2A/0x84/0xE4 | ACCES | RFUI | RFUI | RFUI
0x2B/0x85/0xE5 | PWD0 | PWD1 | PWD2 | PWD3
0x2C/0x86/0xE6 | PACK0 | PACK1 | RFUI | RFUI

Cuadro 1: Mapa de configuración de registros de seguridad y espejado en familia NTAG213/215/216.

El byte MIRROR contiene las configuraciones del espejado ASCII, se configura con el valor 0x85 Los dos bits más significativos indican que el espejado se realizará sobre el contador (siendo las otras opciones espejar la UID, ambos o ninguno). Los siguientes dos indican en que posición de la página seleccionada se comienza a escribir el dato, en este caso al principio. El bit 2 es la habilitación de modulación fuerte, la cual se deja por defecto en 1 mientras que los demás bits están reservados y se mantienen en 0.

Todos los bytes notados “RFUI” son de reserva y se mantienen en su valor por defecto 0x00. El byte MIRROR_ PAGE determina en que página se escribirá el espejo contador. El byte AUTH0 define a partir de qué página se protegen los datos con contraseña, el valor por defecto es 0xFF, es decir que se permite la lectoescritura de todas las páginas, lo habitual es configurarlo en texttt0x04, es decir dejar libres las páginas de información de fábrica y proteger el resto.

El byte ACCES se configura con el valor 0x98, el cual si se analiza bit a bit indica que la contraseña protege contra escritura y lectura, y que el contador está activado. Además, permite establecer un número máximo de intentos de lectura y activar un bloqueo permanente del tag. Estas opciones se descartaron por el riesgo de dejarlo inutilizado accidentalmente, dado que los errores de lectura pueden darse por motivos físicos, teniendo en cuenta que no existe información pública de que se hallla logrado descifrar una contraseña de un tag mediante fuerza bruta.

La página PWD guarda la contraseña del tag, aquí se escribe la contraseña de 4 bytes calculada mediante el hash. La página PACK contiene los dos bytes de confirmación de la autenticación con contraseña que también se calcula mediante el hash.

En su régimen nominal de lectura, el flujo de ejecución sigue una estricta secuencia de validación. Al acercar una tarjeta, se lee su UID y se calcula localmente el hash esperado. Posteriormente, se envía un comando de autenticación al PN532 pasándole la contraseña calculada (NTAG_COMMAND_PWD_AUTH). Si la NTAG devuelve el PACK correcto, se confirma la legitimidad de la tarjeta.

Superada la barrera de seguridad, se emite un comando de lectura rápida (NTAG_COMMAND_FAST_READ) apuntando a la dirección configurada previamente para el Mirror. El valor retornado, que representa el contador de lecturas en formato de caracteres hexadecimales ASCII, es convertido a un entero de 32 bits (strtoul).

Finalmente, la información a reportar se condensa en un payload de 10 bytes: los 7 bytes correspondientes al UID físico de la tarjeta, seguidos de 3 bytes que representan el valor del contador dinámico. Este bloque de datos se despacha mediante la función composer de Ramodbus bajo el comando CMD_NFC, sincronizando el envío mediante un semáforo para asegurar la integridad de la memoria compartida hasta que el despachador de la capa de red confirme su transmisión hacia el servidor.

Se puede, mediante un comando de las NTAG, acceder al valor del contador de forma directa, sin tener que leer un registro ni convertirlo desde ASCII a un número, pero este comando no aumenta el contador como una lectura, por lo que para usarlo debería realizarse una lectura a un registro cualquiera, lo cual agrega puntos de falla en la comunicación del tag con el módulo.

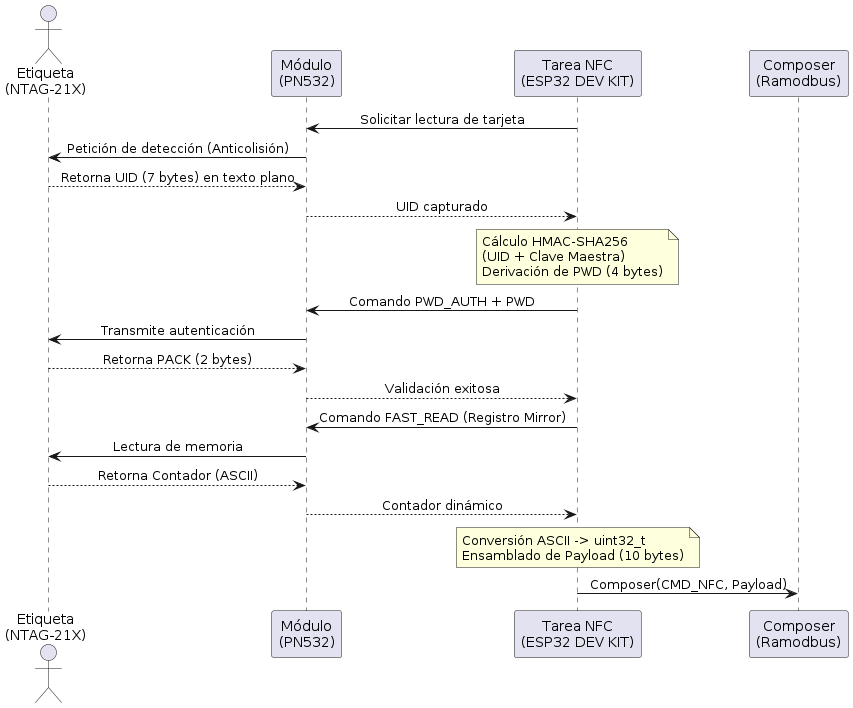
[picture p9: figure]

Figura 9: Diagrama UML de secuencia de la validación de un tag NFC

### 5.2.7. Comunicación con la ESP32-CAM

Para comunicar el controlador principal con el módulo de la cámara, se estableció una comunicación UART, asociada al periférico UART 2 del ESP32.
El protocolo UART está diseñado para conexiones punto a punto y permite la comunicación full duplex, lo que simplifica esta implementación respecto a la del servidor, dado que no es necesario preocuparse por arbitrajes ni colisiones. Asimismo, al ser una comunicación menos crítica y de menor distancia, se reemplazó el CRC como método de verificación de tramas por un checksum.
La librería uart_cam abarca tanto la recepción y el envío de datos, como su procesamiento, “resumiendo” las dos bibliotecas que se utilizan en la comunicación principal.
La tarea cam_uart_rx_task es muy similar a su contraparte de la UART 1, solo que valida en el acto el checksum y, si correspondiera envía el mensaje de error. Posteriormente, retransmite la información recibida (confirmaciones de acciones) al servidor mediante el composer
Para el envío de datos se programó la función cam_uart_send, que calcula el checksum y envía la trama. Esta simpleza se debe que al tratarse de una comunicación full duplex, el ESP32CAM siempre está “escuchando” y no se requieren de condiciones previas para transmitir un mensaje.
Se desarrollaron también módulos relativos a las funcionalidades de la ESP32-

CAM, que actúan como puentes entre esta y el servidor.

### 5.2.8. Comando de la conectividad WiFi

Para administrar la conexión de la ESP32-CAM a la red local de la institución se desarrolló un módulo intermedio que se comunica con el servidor de forma directa y replica las órdenes al periférico. El WiFi se comanda mediante un comando de flujo, es decir que tiene un payload determinado. Se decidió utilizar un solo comando para administrar todos los casos posibles desde la misma tarea. Se definió que el payload máximo admisible en una trama sea de 10 bytes, la cantidad exacta para las UID y los tres bytes del contador en las transacciones NFC. No se definió un número mayor para ahorrar memoria, ya que se reserva memoria para n buffers de mensaje de longitud igual. Esto pone en apuros mensajes que puedan llegar a ser más extensos, como por ejemplo las credenciales de conexión a la red. Es por esto que se estableció que, de ser necesario, se subdivida el payload en trozos o chunks, quedando el payload definido de la siguiente forma:

Byte 0: Subcomando, reconoce cuatro posibles, dos de ellos no requieren más payload y los otros dos sí.

Byte 1: chunk actual

Byte 2: cantidad total de chunks

Bytes 3 al 9: datos

De forma tal que se envían de máximo siete bytes de información por vez. Los subcomandos que conllevan payload son los de cambio de SSID (Nombre de la red) y de contraseña de acceso. Los restantes son una orden de conectar y desconectarse de la red, esto para mantener el sistema desconectado fuera de horario de uso, ya que la antena de radio requiere un consumo de energía no despreciable.
La tarea que reacciona a la llegada de mensajes se dedica a parsear los subcomandos, en el caso de las credenciales, las almacena localmente ya armadas, y apenas se cambien ambas las envía a la ESP32-CAM. En el caso de las órdenes directas, las retransmite directamente.

### 5.2.9. Comando de la cámara

El módulo intermedio de la cámara realiza funciones similares. Se compone de dos tareas. Una reacciona al semáforo del comando CMD_TAKE_PH, liberado por una orden del servidor o bien por el callback de la interrupción del pulsador, y envía la orden de tomar una fotografía al módulo de la cámara.
La otra tarea reacciona al comando de flujo que establece la URL del servidor HTTP al cual deben transmitirse las imágenes. El payload de este comando consta de cuatro bytes que conforman la dirección IP del servidor y otros dos que representan el número de puerto, la tarea genera una string del tipo “http://192.168.XX.XX:XXXX/upload” y la transmite al controlador secundario.

### 5.2.10. Prioridades de las tareas

Dada la naturaleza apropiativa del código, resulta indispensable definir correctamente las prioridades considerando la importancia de la ejecución de estas, en primer lugar para el correcto funcionamiento del sistema y en segundo para garantizar una experiencia de usuario fluida.

Módulo | Tarea | Prioridad FreeRTOS
Sistema | Reset | 20
UART-RS485 | Rx | 10
Protocolo | Dispatcher | 9
Protocolo | Parser | 8
DIO | Puerta | 7
NFC | Lectura de tags | 6
UART-Camara Rx - cámara | 5
NFC | Arbitraje | 4
Wifi | Wifi | 3
Camara | Camara | 3
NFC | Configuración | 3

Cuadro 2: Distribución y esquema de prioridades de las tareas en FreeRTOS.

La prioridad máxima se corresponde a la tarea que ataja los comandos de reset, dado que si se manda a reiniciar por software no tiene sentido que se proceda la ejecución de otras tareas.
Le sigue el receptor de tramas del bus serial, dado que el sistema debe estar siempre atento a las encuestas del maestro. La siguiente tarea en despertar cronológicamente es el parser, el cual luego de procesar la trama recibida notifica al dispatcher, el cual se configuró con prioridad mayor para priorizar las respuestas inmediatas. La máxima prioridad del sistema es responder al servidor.
Luego le siguen las funcionalidades, donde la más prioritaria es la de abrir la puerta, ya que es lo más perceptible por el usuario. Siguiendo una lógica similar, la lectura de tags debe realizarse de forma rápida para asegurar fluidez en el acceso. Las funcionalidades relativas a la ESP32-CAM son menos críticas en tiempo y demorarse ante las demás sin que esto afecte el sistema o sea percibido por algún actor humano
Finalmente, la tarea de configuración de tags se crea dentro de la tarea NFC principal, por lo que debe crearse con menor prioridad. El árbitro tiene menor prioridad que la tarea de lectura para que no pueda interrumpir un intento de acceso.

### 5.3. Firmware del ESP32-CAM

Para el kit de desarrollo ESP32-CAM, la arquitectura de software resulta a grandes rasgos una versión simplificada de la del controlador principal, manteniendo la arquitectura de tareas de FreeRTOS para manejar las distintas responsabilidades y reaccionar a los distintos eventos de forma concurrente, respondiendo a comandos externos y devolviendo confirmaciones e información relevante.

### 5.3.1. Comunicación UART

La ESP32-CAM ocupa el rol de un periférico, por lo que si bien la comunicación es punto a punto y no podemos hablar de un “esclavo”, conceptualmente se puede decir que está en una jerarquía inferior al controlador principal, es por eso que el comportamiento de la librería uart se asemeja más al de un esclavo Ramodbus simplificado. Se tomó como base la misma librería uart_cam pero adaptada. La configuración se mantuvo tal cual, utilizando incluso el mismo periférico UART 2. La tarea cam_uart_rx_task es bastante similar a su contraparte, la recepción y validación se mantienen, mientras que el parseo se comporta de manera similar a ramobdus, liberando semáforos o transmitiendo buffers de mensaje según corresponda, resolviéndose de forma “manual” dentro de la misma tarea dada la reducida cantidad de opciones de ruteo.
Se añaden funciones getter para el buffer de mensajes de WiFi, el buffer de URL del servidor HTTP y el semáforo que indica tomar una fotografía.
Se mantiene también la función de envío cam_uart_send.

### 5.3.2. Conexión WiFi

El módulo de gestión WiFi en la ESP32-CAM tiene como propósito administrar la interfaz de red inalámbrica en modo Station. Al operar como un periférico subordinado al controlador principal, su comportamiento está supeditado a los comandos recibidos por UART, pero mantiene cierta autonomía para gestionar la persistencia del enlace y el ahorro de energía.
Como se detalló en el apartado del controlador principal, si bien este recibe las credenciales divididas en chunks debido a las limitaciones de memoria de los buffers de mensaje, este se encarga de reensamblarlas. Por consiguiente, la ESP32-CAM recibe las credenciales (SSID y Password) en estructuras planas y completas. Para manejar el flujo de red de forma concurrente sin bloquear la recepción de comandos, la arquitectura se dividió aprovechando las herramientas de FreeRTOS y el framework nativo del microcontrolador:

Recepción de comandos (app_wifi_com_task): Esta tarea permanece bloqueada aguardando datos en un MessageBuffer alimentado por la recepción de la UART. Al recibir una trama, evalúa el primer byte para identificar el comando. Si se trata de credenciales de red, actualiza los arreglos globales en RAM de forma segura. Si recibe un comando de acción (WFON o WFOFF), invoca las funciones del driver WiFi para encender, apagar o reconectar el periférico, estableciendo una bandera fundamental: WIFI_MUSTBE_BIT.

Gestión de eventos (event_handler): Actúa como un callback que reacciona a los eventos internos del sistema (como desconexiones físicas o la obtención de una IP). Aquí reside la resiliencia del enlace: si ocurre una desconexión accidental, se verifica el estado de la bandera WIFI_MUSTBE_BIT. Si el sistema “debería” estar conectado, el handler dispara automáticamente una secuencia de reintentos sin necesidad de intervención externa.

Mantenimiento y persistencia (app_wifi_task): Una tarea de bajo peso dedicada a reaccionar a las banderas de un EventGroup (s_wifi_event_group). Su función principal es descargar de tareas bloqueantes al flujo principal, encargándose de los ciclos de reconexión y de escribir las nuevas credenciales en la memoria no volátil (NVS), garantizando que la cámara recuerde la red tras un reinicio.

Finalmente, la comunicación fluye también en sentido inverso. Cuando la ESP32-CAM logra conectarse a la red y el router le asigna una dirección, el evento IP_EVENT_STA_GOT_IP empaqueta los 4 bytes correspondientes a la dirección IPv4 obtenida y los transmite de regreso al ESP mediante la función cam_uart_send para que este los retransmita al servidor. Esta confirmación es crítica para que el servidor central sepa a qué IP exacta debe realizar las peticiones HTTP a la hora de capturar una fotografía.

### 5.3.3. Cámara

El módulo encargado de la captura de imágenes toma como base el componente oficial del fabricante espressif/esp32-camera. Esta biblioteca provee una API de alto nivel que abstrae la complejidad de los buses I2S e I2C (SCCB), requiriendo únicamente la inicialización mediante una estructura de configuración. Los parámetros se adaptaron de los ejemplos provistos por el fabricante, estableciendo el formato de salida en JPEG y la resolución en SVGA para equilibrar calidad de imagen y uso de memoria.
Para mantener la concurrencia del sistema, la lógica se dividió en dos tareas independientes de FreeRTOS:
La url_task aguarda la recepción de una trama UART proveniente del controlador principal que contiene la dirección IP y el puerto del servidor HTTP. Al recibirla, formatea la URL de destino y la almacena en la memoria no volátil (NVS) mediante nvs_set_str. Esta persistencia permite que el periférico mantenga su configuración ante reinicios o cortes de energía, inicializando el cliente HTTP sin requerir una nueva intervención del controlador principal.
Mientras tanto la camara_task es la tarea central del módulo. Permanece bloqueada a la espera de que se libere el semáforo cmd_sem, disparado por un evento de acceso (como la validación de una credencial NFC). Al activarse, la rutina ejecuta una secuencia crítica para asegurar la calidad de la captura:
1. Purga de Frame Buffer: Debido al comportamiento del controlador DMA de la cámara, el búfer suele retener una imagen capturada instantes antes o presentar artefactos visuales tras períodos de inactividad. Para solucionar esto, el firmware solicita una primera captura que es descartada inmediatamente (dummy frame), forzando al hardware a exponer y capturar una nueva imagen.
2. Iluminación y Captura: Simultáneamente a la solicitud del segundo frame (la captura real), se enciende el LED de alta potencia de la placa para garantizar la correcta iluminación del sujeto, apagándose inmediatamente al obtener los datos.
3. Transmisión HTTP y Tolerancia a Fallos: La imagen en formato JPEG se envía mediante un método POST al servidor. Se implementó una lógica de resiliencia que realiza hasta tres reintentos en caso de fallos de red o de respuesta del servidor (tiempos de espera o rechazos). Si el fallo persiste, se liberan y reconstruyen los recursos del cliente HTTP para evitar bloqueos futuros.

Finalmente, de forma independiente al resultado de la transacción HTTP, se transmite una trama de confirmación por UART (UART_CAM_PH_CMD). Esta señal impacta en el controlador principal para que libere el flujo lógico e informe al servidor central, el cual será el responsable final de verificar el ingreso físico del nuevo archivo de imagen.

## 6. Servidor

El servidor constituye el núcleo del sistema. Consiste en una computadora con una distribución de Linux como sistema operativo, conectada por un lado al bus RS-485 mediante una interfaz serie y, por otro, tanto a la red de área local de la institución como a Internet.
La elección de Linux como entorno de ejecución otorga portabilidad al sistema, permitiendo su despliegue sobre diversas plataformas de hardware según la disponibilidad y los requerimientos de la instalación. Durante la etapa de desarrollo y pruebas, se utilizó una computadora portátil con Ubuntu junto a un convertidor USB a RS-485 estándar. Para la puesta en producción en campo, el cambio fundamental a nivel de hardware consiste en la incorporación de un convertidor de grado industrial con aislamiento galvánico (optoacoplado y con protecciones ante transitorios), lo cual previene bucles de masa (ground loops) y garantiza la seguridad eléctrica tanto del equipo anfitrión como del bus de comunicaciones.
Cumplido este recaudo, el software puede desplegarse en cualquier servidor o PC convencional que ejecute Linux. Asimismo, una alternativa viable y compacta es el empleo de una computadora de placa reducida (Single Board Computer o SBC), como una Raspberry Pi. Esta opción resulta especialmente conveniente cuando no se dispone de infraestructura de servidores previa o cuando se requiere ubicar la unidad de control en proximidad física al tendido del bus. Entre las ventajas añadidas del uso de una SBC destacan su bajo consumo energético y la posibilidad de prescindir de convertidores USB intermedios mediante el conexionado de un transceptor RS-485 directamente a los pines UART/GPIO del procesador.
La arquitectura consta de cuatro procesos:

Un gestor de la interfaz serial que se encarga del polling y los comandos hacia los esclavos.
La interfaz de usuario.
El servidor HTTP.
Un broker MQTT para comunicar los procesos entre sí.

La interfaz serial no solo gestiona la comunicación con los terminales, sino que también se ocupa del monitoreo de la conectividad de estos por ambas vías y resuelve internamente todo lo relacionado con los accesos mediante tags NFC.
El servidor HTTP se implementa sobre una instancia de Node-RED y también incorpora algunas funcionalidades auxiliares.
La interfaz de usuario está programada en Python y utiliza la API de la aplicación de mensajería “Telegram”.

### 6.1. Programa principal

El dominio de la interfaz serial se ocupa de realizar las encuestas periódicas, verificar la conectividad y comandar a los esclavos, así como de procesar los datos recibidos por estos.
Está programado en Python y se compone de varios módulos. Cada módulo incluye funciones que pueden ser llamadas desde otros archivos así como procesos que se disparan en hilos paralelos de ejecución (librería threading.py). El programa principal main.py crea los procesos y dispara los hilos.

En principio esta arquitectura presenta similitudes con la de los terminales implementados en FreeRTOS, pero existen diferencias clave que hay que mencionar, la primera es que si bien los hilos se ejecutan mediante una estructura apropiativa gestionada por un scheduler que vive en el kernel del sistema operativo no existe en este caso tal cosa como asignación de prioridades, todos los hilos en estado ready comparten time slices del mismo tamaño.
Otro punto clave es el GIL de Python o “Global Interpreter Lock”, un semáforo de exclusión mutua (mutex) diseñado para proteger las estructuras de memoria internas y el mecanismo de conteo de referencias frente a condiciones de carrera. Por esto, solo un hilo ejecuta código Python a la vez por proceso, impidiendo el paralelismo real en tareas de cálculo intensivo. Sin embargo, para operaciones de entrada/salida (como la comunicación serie o de red), el GIL se libera durante las esperas, permitiendo una concurrencia fluida y eficiente entre módulos.
A continuación se describen los distintos módulos que componen el sistema.

### 6.1.1. Módulo de interfaz serial

Este módulo es la interfaz serial del servidor e implementa la ejecución de un maestro del protocolo “Ramodbus”. El hilo principal de ejecución no requiere de una máquina de estados, sino que es secuencial. Intercambia información con los otros módulos mediante una cola de entrada y sendas colas de salida para cada nodo. Las direcciones o identificadores de los nodos activos se definen en una tupla dentro del archivo de configuración. El hilo de comunicaciones itera cíclicamente sobre estos identificadores ejecutando la siguiente secuencia por cada nodo:

1. Revisa el estado del nodo, si está marcado como desconectado, se omite su consulta para no penalizar el tiempo de ciclo.
2. Comprueba si existen comandos pendientes en la cola asociada a dicho nodo.
3. Si la cola contiene elementos, extrae el comando y lo transmite; en caso contrario, envía una trama periódica de consulta (polling).
4. Espera la respuesta del esclavo, luego de que responda o de un timeout pasa al siguiente nodo y repite.

Si un nodo no responde, se incrementa un contador de fallos consecutivos que se reinicia ante cualquier recepción válida. Al superarse un umbral predefinido de reintentos fallidos, el nodo pasa al estado desconectado y se emite una notificación al resto del sistema
Cuando se recibe una respuesta válida, si se trata de una simple confirmación (ACK) se descarta. Si en cambio contiene datos útiles, se encapsula en un diccionario con el formato { “id_nodo”: id_nodo, “cmd”: cmd_recibido, “payload”: payload_recibido }
La construcción de tramas se centraliza en una función encargada de estructurar el encabezado y computar el código de redundancia cíclica (CRC). Por su parte, la rutina de recepción bloqueante valida la dirección del destinatario, el encabezado y la coherencia del CRC, retornando la carga útil decodificada o el código de error correspondiente.
En el archivo de configuración se definen tres parámetros que afectan a la velocidad de la comunicación.

Velocidad de transmisión (Baud rate): Tasa de transferencia en baudios del enlace físico.
Tiempo de espera (Timeout): Tiempo límite que el maestro aguarda la respuesta del esclavo. Se establece con un margen superior al tiempo de respuesta nominal; por ello, la exclusión de nodos desconectados resulta indispensable para evitar retardos ociosos en el barrido.
Intervalo entre consultas (Inter-polling delay): Pausa deliberada entre transacciones consecutivas para no saturar el medio y otorgar tiempo de procesamiento a los terminales.

### 6.1.2. Módulo de control

Este módulo, implementado en el archivo nexo.py, centraliza la lógica de control del servidor y la coordinación interna. Define la función pública encolar(), empleada tanto por rutinas internas como por otros módulos del proceso para ingresar comandos en las colas de salida sin interactuar directamente con el puerto serie. s Asimismo, ejecuta un hilo dedicado a procesar los elementos de la cola de entrada. Ante eventos de desconexión de terminales, publica una alerta en el tópico MQTT correspondiente; mientras que ante la recepción de tramas de datos, invoca a la rutina de análisis sintáctico (parser) para despachar la ejecución hacia la subrutina correspondiente según el comando recibido.

### 6.1.3. Módulo MQTT

Este módulo encapsula el cliente MQTT del proceso. Provee una función de publicación accesible por los demás módulos y ejecuta un hilo de escucha (listener) que, mediante su propio analizador sintáctico, procesa los mensajes entrantes según el tópico y la carga útil (payload) recibida.
En general hay tres familias de tópicos anidadas en el tópico “sbc”. El módulo nexo publica en el subtópico “sbc/notify” para disparar las alertas de desconexión o clonación de tags, y en “sbc/status/<nodo>” donde en <nodo>figura una string del número de nodo en formato hexadecimal. En estos tópicos se informan eventos en el payload, por ejemplo OK_PUERTA es el aviso de que el comando de apertura impactó sobre el terminal y el acceso fue desbloqueado y OK_FOTO informa que el terminal intentó (con o sin éxito) transmitir una imagen mediante HTTP.
La tercera rama corresponde a los tópicos de comandos bajo el formato sbc/cmd/, a los cuales el cliente permanece suscrito para recibir peticiones emitidas desde la interfaz de usuario. En este caso, la carga útil especifica el nodo destinatario; por ejemplo, si se recibe un mensaje en sbc/cmd/abrir con el valor 0x0A, el módulo encola una orden de apertura dirigida al nodo 10, la cual se transmitirá físicamente durante su próxima consulta en el bus RS-485. El payload de algunos mensajes de este tópico incluyen además del número de nodo el ID del chat del usuario que los solicitó, el cual es utilizado en el proceso de Node-RED.

### 6.1.4. Módulo de gestión de red

El módulo de red realiza las funciones de conexión y mantenimiento de las conexiones a la red local de los terminales. Incorpora el módulo subprocess, el cual permite inyectar comandos a la terminal del sistema operativo. Implementa funciones que mediante comandos de terminal obtienen la dirección IP del servidor, el nombre de la red wifi y la contraseña de acceso, para esta última es necesario tener privilegios de superusuario al ejecutar el script, esto no representa un problema en producción ya que, al correr como servicios todos los procesos se ejecutan desde el usuario raíz. Los datos obtenidos sirven como argumentos de otras dos funciones que transmiten las configuraciones de red a los nodos, una toma la IP y arma la trama de 6 bytes de IP + puerto para el servidor HTTP (por defecto se utiliza el puerto 1880) y la otra toma el nombre de la red y la contraseña, los segmentan en chunks de no más de 7 bytes y arman las tramas de formato subcomando + chunk actual + chunk totales + data, para indicar al terminal que modifique sus credenciales de acceso a la red. Ambas funciones barren con la tupla de nodos y para cada uno encolan los mensajes que hagan falta para configurar la conexión. Estas funciones se ejecutan al inicio del programa desde el main para que el sistema inicie con los nodos configurados. También se incluyó un hilo de monitoreo, el cual periódicamente recorre un diccionario que asocia cada nodo con su IP reportada y verifica la conexión mediante un ping. Ante sucesivas fallas en el ping, se encola un comando de reconexión al terminal.
El diccionario es global y está definido en el archivo de configuración. Lo rellena el parser como respuesta a los comandos de WiFi provenientes del nodo, los cuales reportan la IP de este.
Esto se definió así dado que al ocupar una red ya existente, el sistema puede adaptarse a las asignaciones de IP dinámicas por DHCP del router.

### 6.1.5. Módulo de validación de accesos por tags NFC

Este módulo implementa toda la lógica de accesos mediante tags NFC. Gestiona la actualización del “padrón” de accesos, la validación de solicitudes y el registro histórico local.
Incorpora las librerías os para operar con archivos, csv para leer y escribir archivos de este formato y datetime para poder incorporar fecha y hora en los registros.
El padrón es un archivo csv que incluye los campos UID, contador, titular y habilitación. el UID y el contador son los datos recibidos desde el terminal que deben validarse. El titular es el dueño del tag asociado y la habilitación es un campo booleano que permite desactivar tags ya sea manualmente mediante la modificación del archivo o de forma automática cuando se detecta una clonación.
Como la funcionalidad de acceso debe ser dinámica, no se puede consultar al archivo en cada solicitud, la función cargar_padron_a_ram() rellena un diccionario con las UID, contadores y titulares de los tags habilitados. Esta función se llama al iniciar el proceso o mediante la llegada de un comando por MQTT desde la interfaz de usuario.
La trama de que envían los terminales consta de 7 bytes para el UID y 3 bytes para el contador. El procesamiento de las tramas lo realiza el parser mediante funciones del módulo de acceso, primero, con los datos recibidos llama a la función validar, la cual revisa primero que el UID coincida con alguna de las cargadas en RAM y luego que el contador sea válido mediante los siguientes criterios:

El contador recibido no puede ser menor al guardado, ya que esto implicaría una clonación

El contador recibido no puede ser mucho mayor al guardado, ya que esto implicaría que fue leído por fuera del sistema, se deja un margen para posibles fallas, por ejemplo una lectura válida con el servidor caído.
Un caso excepcional es si el contador guardado tiene el valor -1, en este caso se toma cualquier valor como válido ya que se le asigna -1 a los tags nuevos a incorporar, o por si se quiere volver a incorporar un tag que fue deshabilitado anteriormente, ya que pudo seguir siendo leído por los terminales y aumentando el contador de forma indefinida.

En el caso de que la solicitud sea válida, la función actualiza el contador tanto en RAM como en el archivo y retorna éxito. Si la función retorna éxito, el parser encola un comando de apertura y posteriormente llama a la función registrar_evento_en_log la cual registra en un csv la entrada válida. En el caso de que el UID no se encuentre en el padrón, la función de validación devuelve “DESCONOCIDO” y el parser registra el evento.
Si el fallo en la validación está en el contador, la función de validación deshabilita el tag tanto en RAM como en el padrón y devuelve “CLONACIÓN”. El parser además de registrar el evento, dispara una alarma por MQTT para que la interfaz notifique los usuarios.

### 6.2. Instancia de Node-RED

Para resolver la recepción HTTP y la automatización de tareas secundarias sin añadir complejidad computacional innecesaria al código principal en Python, se implementó una instancia de Node-RED. Esta herramienta permite orquestar flujos de datos de forma ágil mediante una interfaz gráfica basada en la interconexión de nodos, lo que resulta ideal para mantener un orden visual claro. Dado que su conveniencia disminuye frente a lógicas con demasiados escenarios condicionales, su integración en esta arquitectura se delimitó estrictamente a la ejecución de procesos simples, aprovechando su rapidez de implementación y la disponibilidad de bloques preconfigurados (incluyendo funciones programables en JavaScript) para interactuar con diversos protocolos.
El principal uso que se le da en el sistema es el de servidor HTTP. Mediante un bloque POST recibe las imágenes transmitidas por los terminales y las guarda en un directorio específico mediante un nodo de archivo.

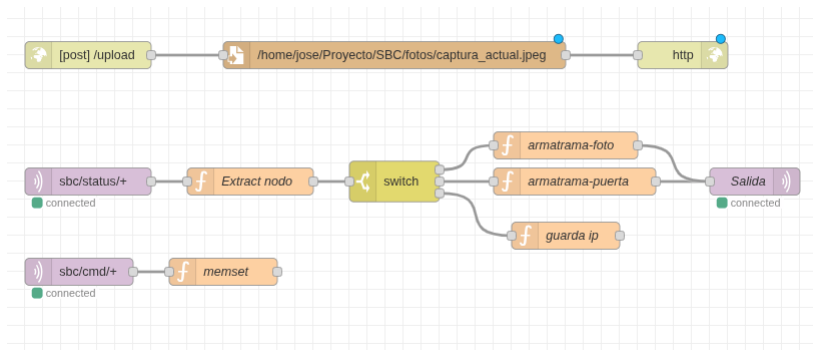
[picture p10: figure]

Figura 10: Flujo de automatización de endpoint HTTP.

Este flujo también incorpora un cliente MQTT que suscribe al tópico de comandos, el cual guarda en memoria el nodo y el ID del chat del usuario que lo disparó. También suscribe al tópico de status, para retransmitir la información al tópico sbc/notify. Esto lo hace para el caso de los comandos de apertura, para enviar la confirmación solo al usuario que la solicitó. En el caso de las fotografías, revisa si fue solicitada por un usuario y lo utiliza como destino, si la fotografía se corresponde a alguien solicitando el acceso desde fuera, indica que se transmita a todos los usuarios. El payload de la foto es un JSON que indica el evento (si la foto fue solicitada por un usario o “espontánea”, es decir por solicitud de acceso de un visitante), el destinatario y la ruta absoluta de la fotografía.

Otro flujo simple que se implementó es la carga histórica del registro de accesos. Mediante un nodo de inyección programado para dispararse diariamente a cierta hora, se envía un email con el archivo csv de registros que contiene los correspondientes a ese día. El flujo utiliza un nodo de archivo para saber dónde “buscar” el registro, luego un nodo de función para formatear el mensaje y finalmente un nodo e-mail, el cual está configurado con la dirección de destinatario así como con una clave de aplicación, en este caso de google para trabajar con Gmail.

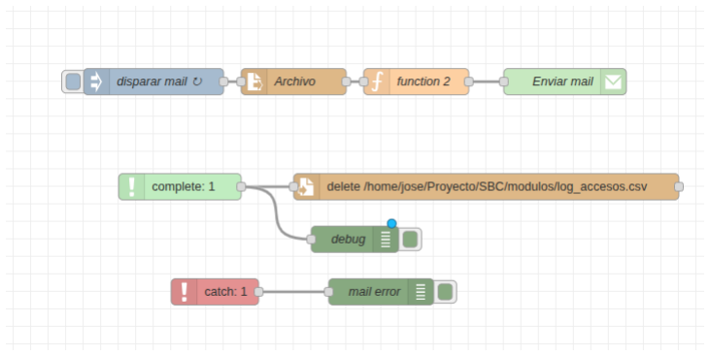
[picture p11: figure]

Figura 11: Flujo de automatización de envío periódico de registros de acceso.

El nodo complete se asocia a otros nodos y se dispara cada vez que el objetivo realiza su función, al apuntarlo al nodo de e-mail, sabe cuando el correo se envió exitosamente y comanda un nodo de archivo para que elimine el registro viejo, así cada archivo solo representa al día pasado. En el caso de error, por ejemplo que a la hora de enviar el correo el servidor pierda la conexión a Internet, no se borra el archivo y sigue acumulando registros hasta que se envíe.

Hay un tercer flujo desactivado que permite inyectar tramas por el bus RS-485. Utiliza nodos de inyección manual conectados a un nodo de función que calcula y añade el CRC y envía la trama a un nodo serial. También incluye un nodo serial de entrada conectado a un nodo de debug para observar las respuestas. Este flujo se utilizó en el desarrollo para probar el protocolo y se mantuvo para pruebas. Si bien se tuvo que desactivar para no generar conflictos con el uso del puerto serie del servidor, que ahora utiliza el programa principal, se mantiene como una herramienta de debug y pruebas de actualizaciones en el futuro.

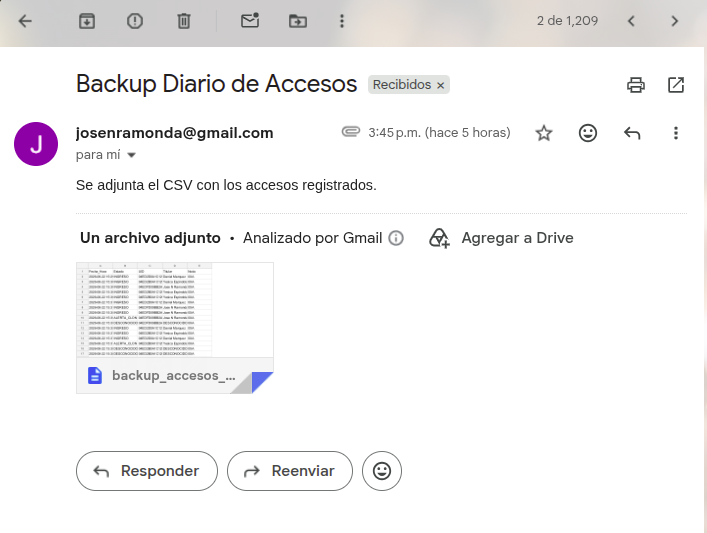
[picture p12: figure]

Figura 12: Correo electrónico con registro histórico enviado desde Node-Red.

### 6.3. Interfaz de Usuario

La interacción principal con el sistema de control de acceso se centraliza a través de un bot en la aplicación de mensajería instantánea Telegram. Esta plataforma fue seleccionada frente a alternativas populares como WhatsApp debido a que ofrece una API [10] gratuita, abierta, ampliamente documentada y accesible. En contraste, la API de WhatsApp requiere un registro empresarial, es de pago y presenta un entorno más cerrado. Adicionalmente, esta decisión responde al requerimiento explícito del cliente de mantener las funcionalidades de control de acceso separadas de sus comunicaciones cotidianas, evitando que los comandos y notificaciones de seguridad se pierdan entre otras conversaciones.
El bot permite automatizar respuestas en formato de chat e implementar comandos e interfaces gráficas basadas en menús. La aplicación fue desarrollada en Python y se ejecuta como un proceso completamente independiente. Esta decisión arquitectónica permite desacoplar la interfaz del resto de las tareas del sistema, aislando posibles puntos de fallo.
Asimismo, la biblioteca Python-telegram-bot requiere el uso nativo del módulo asyncio para el manejo de tareas asíncronas. Dado que este módulo implementa un esquema de concurrencia colaborativa, su convivencia con el módulo threading tradicional dentro del mismo proceso resulta compleja y propensa a colisiones, lo que refuerza la necesidad técnica de aislar el bot en su propio espacio de ejecución.

### 6.3.1. Arquitectura y Máquina de Estados

El núcleo de la interfaz se basa en una Máquina de Estados Finitos (MEF) implementada mediante un ConversationHandler. Este diseño previene comportamientos erráticos al restringir las acciones del usuario según su estado actual en el sistema. Los estados definidos son:

ESPERANDO_USER y ESPERANDO_CLAVE: Flujo inicial de autenticación.

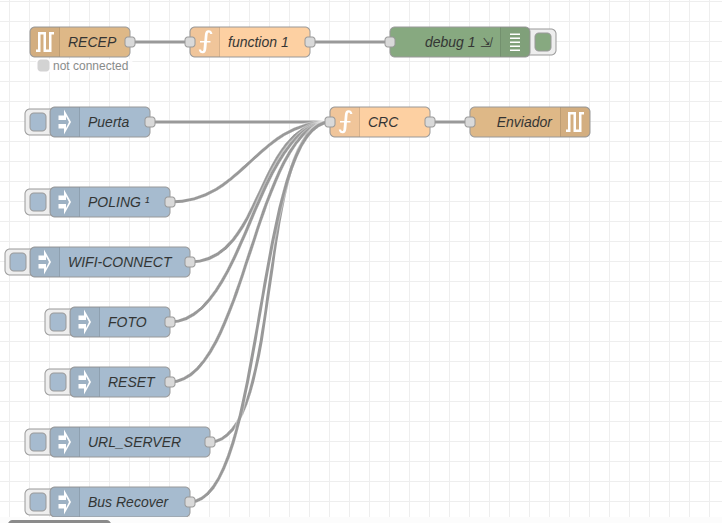
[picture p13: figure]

Figura 13: Flujo de inyección de comandos Ramodbus al bus serial.

EN_MENU_USUARIO: Estado de reposo donde el sistema aguarda interacciones a través de los teclados en línea (botones).
ESPERANDO_CLAVE_ADMIN: Estado transitorio para la elevación de privilegios.

Cualquier entrada de texto no reconocida mientras el sistema se encuentra en estado de menú es capturada e ignorada de forma segura para no romper el flujo de la conversación.

### 6.3.2. Módulo de Autenticación y Roles

La seguridad de la interfaz se gestiona de forma local a través del archivo credenciales.json. El sistema clasifica a los individuos en tres categorías: Invitados (sin acceso), Usuarios Estándar (pueden operar puertas y cámaras) y Administradores (pueden auditar el sistema y gestionar el hardware). Al ingresar exitosamente, el sistema vincula de forma permanente el chat_id numérico de Telegram con el perfil del usuario. Esto es fundamental para el posterior enrutamiento de notificaciones asíncronas y alertas de seguridad específicas a cada individuo.

### 6.3.3. Navegación y Menús Interactivos

Para minimizar los errores de tipeo, la operación se realiza íntegramente mediante teclados en línea (InlineKeyboardMarkup). Los menús son dinámicos; por ejemplo, la selección de hardware lee directamente las direcciones físicas reales del bus de los nodos (como 0x0A para el Acceso Frente) desde la configuración (botconfig.py) y las embebe en la carga útil (callback) de cada botón.
El Administrador cuenta con un panel avanzado que le permite:

Listar el estado y privilegios de todos los usuarios registrados.
Activar o detener el Modo Programación directamente en el hardware de los nodos remotos.
Descargar y actualizar la base de datos física de accesos.

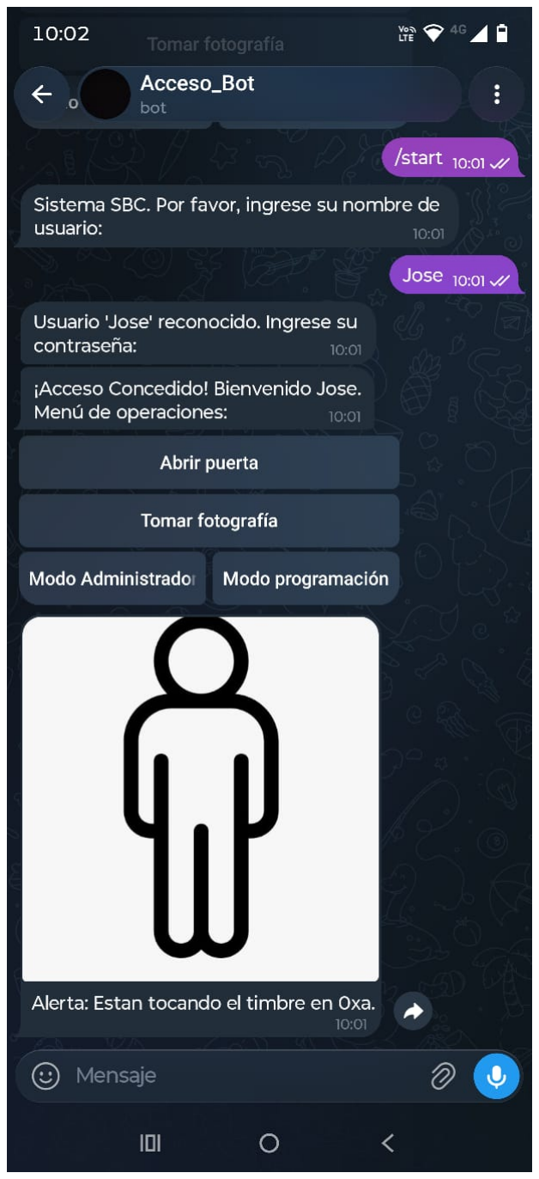
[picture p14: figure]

(a) Validación de acceso y menú de usua-

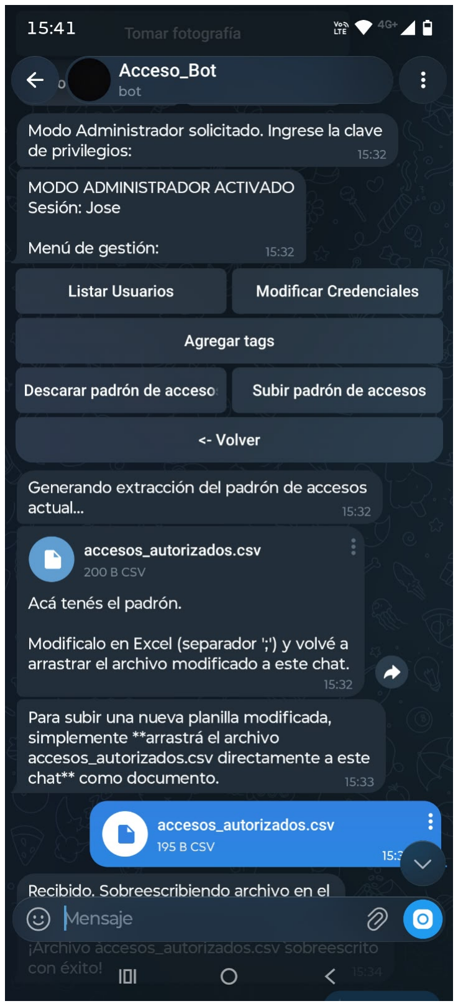
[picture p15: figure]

rio. | (b) Gestión del padrón.

Figura 14: Interfaz de Telegram mostrando la operación normal del sistema.

### 6.3.4. Integración MQTT y Notificaciones Asíncronas

El módulo MQTT.py gestiona dos vías de comunicación simultáneas para comunicar este proceso con el resto del sistema:

1. Emisión de comandos (sbc/cmd/): Ejecuciones síncronas gatilladas por los botones del bot (aperturas, toma de fotografías, inicio de modo programación).
2. Escucha de notificaciones (sbc/notify): Un hilo secundario que se mantiene suscrito al bróker para atajar alertas provenientes de Node-RED o del hardware.

Este hilo secundario cuenta con un bucle de eventos propio (asyncio) que le permite despachar contenido multimedia a los usuarios sin bloquear la ejecución principal de la interfaz. Esto incluye capturas fotográficas de control, alertas tempranas por pulsación de timbres físicos y notificaciones críticas de seguridad (por ejemplo,

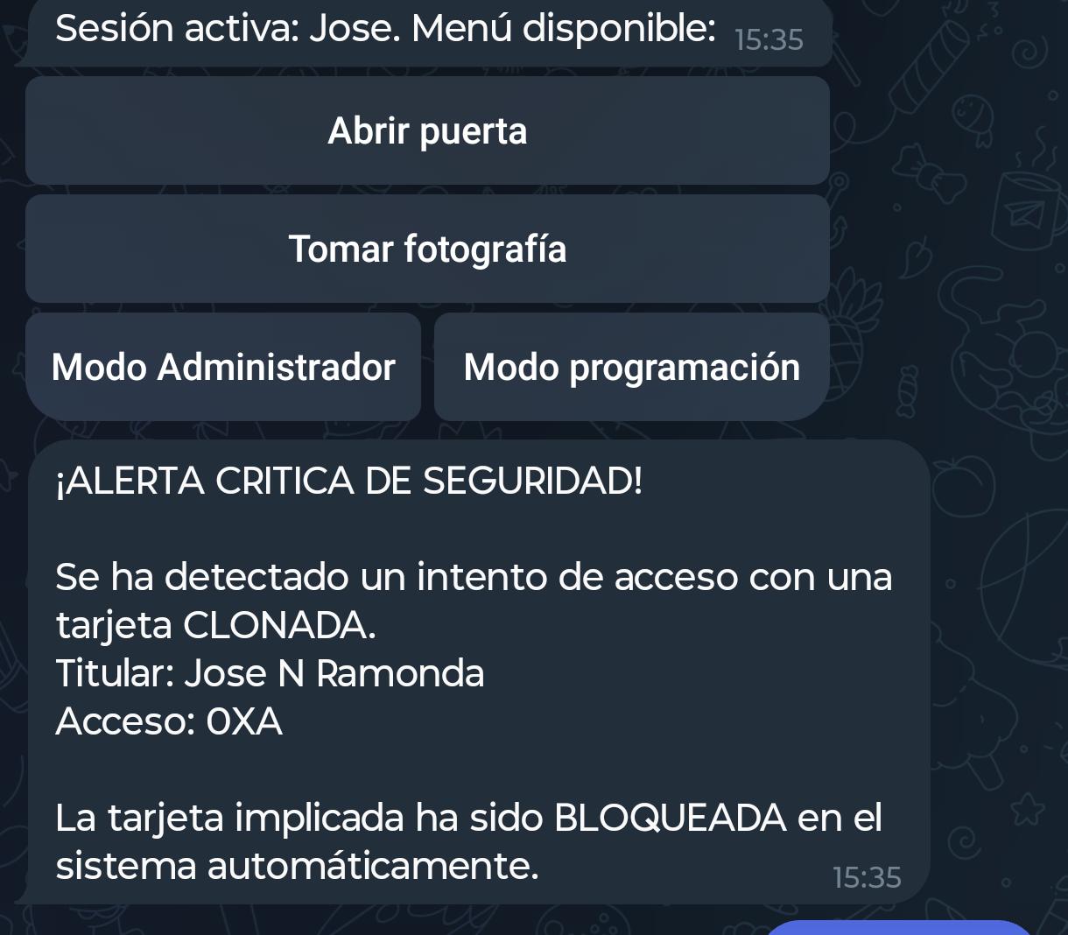
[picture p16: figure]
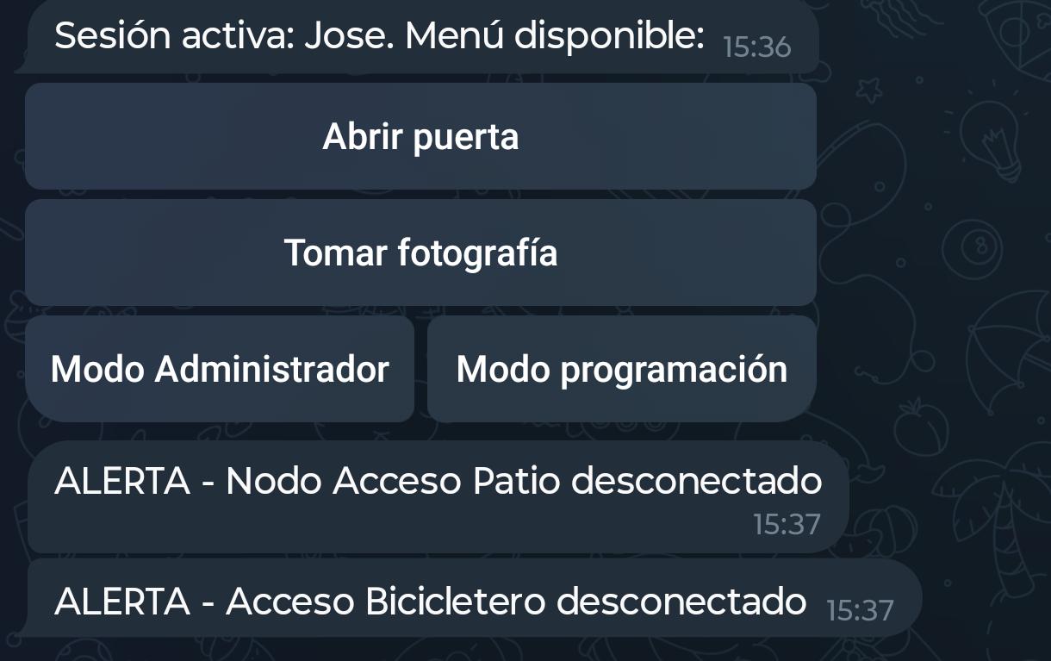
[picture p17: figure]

(a) Alarma de clonación de tags. | (b) Alarma de desconexión de nodos.

Figura 15: Mensajes de alarma configurados en el bot.

el bloqueo automático ante el escaneo de una tarjeta clonada).

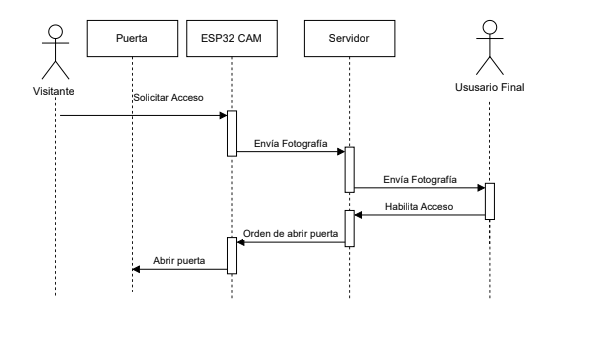
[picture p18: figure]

Figura 16: Diagrama UML de secuencia para la solicitud de acceso mediante fotografía.

### 6.3.5. Gestión Dinámica del Padrón de Accesos

El sistema resuelve la actualización de credenciales NFC de forma intuitiva. El administrador puede solicitar la descarga del archivo accesos_autorizados.csv directamente desde el chat. Una vez editado externamente, la actualización en el servidor SBC se logra adjuntando el nuevo documento a la conversación. El bot ataja el archivo entrante, valida su nomenclatura, lo descarga reemplazando el padrón anterior en el disco y publica un comando MQTT (actualiza) para que el hardware refresque sus listas locales de permisos.

### 6.4. Selección del hardware del servidor y migración a Linux

embebido

Para el despliegue del servidor central y sus pruebas de validación, se migró el entorno de ejecución desde la computadora de desarrollo hacia una computadora monoplaca (Single Board Computer). Si bien las etapas preliminares de integración se llevaron a cabo sobre una Raspberry Pi 3B+, la elección final de producción recayó en la Raspberry Pi Zero 2 W.
Esta decisión responde a un criterio deliberado de optimización y dimensionamiento mínimo de hardware:

Costo y disponibilidad: Es la opción más económica dentro de la familia Raspberry Pi con arquitectura de 64 bits, reduciendo el costo unitario del servidor a menos de la mitad respecto a otros modelos estandar.

Eficiencia energética y térmica: Presenta el menor consumo de potencia (típicamente inferior a 1,5W en carga moderada) y una baja disipación térmica, lo que permite su confinamiento continuo dentro de gabinetes cerrados sin requerir ventilación activa.

Garantía de interoperabilidad hacia arriba: Al comprobarse experimentalmente que la placa más restrictiva de la familia (con 512 MB de RAM) soporta de forma holgada la carga combinada de los servicios, queda demostrado que cualquier modelo superior de la gama es plenamente compatible sin requerir adaptaciones de software.

Al tratarse de un nodo dedicado exclusivamente a tareas de control en segundo plano, se instaló la distribución Raspberry Pi OS Lite (sin entorno gráfico de escritorio), maximizando el espacio de memoria RAM disponible para los procesos del sistema. La migración del código base desde Ubuntu resultó directa gracias a la compatibilidad del entorno Debian, implementándose las siguientes adaptaciones de bajo nivel:

Control del bus RS-485 sin latencia de conmutación: Se evitó el uso de módulos basados en el circuito integrado MAX485, los cuales delegan el control de flujo (transmisión/recepción mediante los pines DE/RE) a una línea ¯ GPIO controlada por software. Dado que el núcleo del sistema operativo Linux no opera en tiempo real estricto, la latencia en la conmutación por software generaba colisiones al recibir las respuestas inmediatas del microcontrolador. En su lugar, se adoptó un módulo transceptor con autodirección de flujo por hardware.

Habilitación de la UART principal nativa: Se utilizaron los pines físicos de expansión (GPIO14/TXD y GPIO15/RXD) vinculados al periférico UART nativo (PL011). Mediante ajustes en el archivo de configuración del gestor de arranque (config.txt), se deshabilitó la consola serie del sistema operativo y se independizó el generador de reloj de la UART de la frecuencia dinámica de la GPU, asegurando una tasa de baudios estable frente a variaciones de carga del procesador.

Gestión de privilegios y seguridad: Con el fin de evitar la ejecución de procesos bajo la cuenta de superusuario (root), el usuario estándar del sistema fue incorporado a los grupos dialout (para el acceso al puerto serie /dev/ttyAMA0) y gpio.

Aislamiento del entorno Python: En cumplimiento de la directriz PEP 668 para distribuciones basadas en Debian moderno, las dependencias del proyecto se instalaron dentro de un entorno virtual (venv) aislado del árbol de paquetes del sistema.

Orquestación de servicios mediante systemd: La lógica de control del bus (main.py) y la pasarela del bot de Telegram (bot.py) se desacoplaron como dos servicios independientes de segundo plano gestionados por systemd, configurados con reinicio automático ante excepciones para garantizar la disponibilidad continua del acceso.

## 7. Seguridad

Un sistema de control de acceso es un tipo de sistema de seguridad y como tal debe estar protegido. Su objetivo es restringir el ingreso a personas autorizadas y aumentar el nivel de protección de las instalaciones mediante mecanismos de identificación y validación de usuarios.
No obstante, es importante señalar que ningún sistema de seguridad puede considerarse completamente invulnerable. En la práctica, las medidas de seguridad no buscan eliminar por completo la posibilidad de un ataque o una intrusión, sino reducir su probabilidad de éxito y aumentar la dificultad, el tiempo y los recursos necesarios para llevarlo a cabo.
El nivel de seguridad implementado debe ser coherente con el contexto de uso, la probabilidad de ocurrencia de amenazas y las limitaciones técnicas y físicas existentes. En este caso, el sistema está destinado al control de acceso de una institución educativa, cuyas necesidades de seguridad difieren de las de entornos críticos como entidades bancarias o instalaciones de alta seguridad.
Asimismo, la eficacia del sistema se encuentra condicionada por características físicas de la infraestructura. Las puertas sobre las que actúa el sistema incorporan un destrabador eléctrico, pero no cuentan con mecanismos de refuerzo estructural adicionales. Por lo tanto, aunque el sistema puede impedir el acceso normal a personas no autorizadas, no puede evitar métodos de ingreso forzado que excedan las capacidades del mecanismo de cierre. En consecuencia, la solución propuesta debe entenderse como una mejora significativa en el control y la gestión de accesos, dentro de las limitaciones físicas y operativas del entorno donde será implementada.

### 7.1. Posibles ataques y vulnerabilidades

La principal vulnerabilidad del sistema es la física y abarca principalmente dos posibles ataques. Primero el ingreso forzado, en este caso el sistema en sí no representa una barrera física sino administrativa. No es lo mismo a nivel legal que una persona no autorizada simplemente abra la puerta y acceda a que ingrese mediante el uso de la violencia. La existencia de la medida de seguridad define la falta que constituye vulnerarla. El otro caso es el de la afectación física del sistema, por ejemplo la desconexión del servidor, el sabotaje del cableado del bus serial, etc. Estos eventos, si bien no permiten el acceso no autorizado como tal, anulan total o parcialmente el funcionamiento del sistema.
Por fuera del sabotaje físico, si un atacante deseara poder acceder a voluntad pasando desapercibido, hay dos caminos posibles:

Clonar un tag NFC válido.
Tomar control del sistema en alguna de sus instancias inyectando comandos de apertura.

### 7.2. Sistema anticlonación

La familia de normas ISO/IEC 18000 establece los requisitos y especificaciones para los sistemas de identificación por radiofrecuencia (RFID) en diversas bandas del espectro. De manera general, un sistema RFID se compone de tres elementos fundamentales: el tag o transpondedor que contiene los datos de identificación, el lector que emite un campo electromagnético para energizar e interrogar a la etiqueta, y el sistema o software de gestión encargado de procesar la información obtenida. Si bien numerosos sistemas tradicionales de control de acceso operan en la banda de baja frecuencia (LF, típicamente a 125 kHz), la disponibilidad, el costo de los módulos de lectura y la facilidad de integración comercial favorecen el uso de la banda de alta frecuencia (HF, 13,56 MHz), estandarizada bajo ISO/IEC 18000-3. Con el objetivo de priorizar la viabilidad económica, el bajo costo unitario de los transpondedores y la rápida reposición por parte de la institución, se optó por operar en dicha frecuencia. No obstante, la amplia difusión y accesibilidad de las herramientas para 13.56 MHz introducen desafíos de seguridad específicos.
En los sistemas elementales de identificación, la primera barrera de autenticación reside en el Identificador Único (“UID”) grabado de fábrica en la memoria de solo lectura del circuito integrado. Aunque existen en el mercado etiquetas con UID reescribible (comúnmente denominadas Magic Cards o CUID), la principal vulnerabilidad radica en la emulación activa. Mediante hardware comercial de bajo costo —como el propio transceptor PN532 operando en modo Target o cualquier teléfono inteligente equipado con NFC y herramientas de emulación de tarjetas (HCE)—, un atacante puede replicar el UID capturado previamente y responder a los comandos del lector de forma idéntica a una credencial legítima.
Dado que el UID se transmite en texto plano durante la fase de inicialización y anticolisión, constituye información pública para cualquier dispositivo que logre proximidad física con el tag. Por este motivo, resulta indispensable migrar de un esquema de identificación pasivo basado en UID hacia el estándar de proximidad ISO/IEC 14443 Tipo A (base de la tecnología NFC), aprovechando la memoria protegida del transpondedor.
Dentro de las alternativas disponibles bajo este estándar, las credenciales Mifare Classic quedaron descartadas debido a las vulnerabilidades estructurales demostradas en su algoritmo propietario Crypto-1. En su lugar, se seleccionaron etiquetas de la familia NTAG21x (específicamente NTAG213/215/216, clasificadas como NFC Forum Type 2 Tag). Estas permiten la protección de su contenido mediante una contraseña de 32 bits. Para que el lector establezca una sesión activa con el tag, debe autenticarse mediante la contraseña grabada en la memoria del chip, ante lo cual este responde con un código de reconocimiento (Password Acknowledge o PACK). Ambos valores se derivan de forma dinámica mediante un algoritmo HMAC-SHA-256: este combina el UID del tag con una función hash criptográfica (SHA-256) y una clave secreta almacenada exclusivamente en el firmware del nodo, garantizando que dicha clave no quede expuesta en la memoria ni en las transmisiones con el servidor central.
El algoritmo HMAC-SHA-256 devuelve siempre 32 bytes, por los cuales se trunca el resultado tomando seis bytes consecutivos, comenzando en determinada posición para incorporar una capa de seguridad ante una filtración de la clave secreta. En este punto obtener los datos para emular un tag completo resulta considerablemente difícil y requeriría de conocimientos y equipo específico, un método podría ser acoplar al sistema una antena que intercepte todo el intercambio, luego estudiando el protocolo descifrar todas las etapas de la comunicación para finalmente emular la uid y transmitir en el momento apropiado el PACK y suplantar a la credencial original. Ante este improbable pero posible caso, se incorporó una medida adicional, que si bien no es preventiva puede detectar una eventual clonación.
Las NTAG cuentan con un contador por hardware, que al activarse aumenta el valor en un registro de tres bytes. Esto solo cuenta lecturas de registros y solo funciona luego de la energización del tag, por lo que si se deja la etiqueta sobre el lector indefinidamente, el contador no aumenta. En la programación de cada tag se incluye un registro al cual el contador se “espeja”, con lo cual el terminal al detectar un tag realiza la siguiente secuencia:

Extrae el UID
Calcula el hash
Se identifica con el tag mediante la contraseña Valida el PACK devuelto
Lee el registro del contador
Envía al servidor los datos UID + contador

Con esto se tiene un primer filtro local en el nodo, que identifica si el tag fue programado para este sistema. Luego el servidor no solo valida que el UID pertenezca a las autorizadas, sino que revisa el valor del contador. En el caso más desfavorable, si un tag clonado se utiliza para acceder y aumenta su contador indefinidamente, al ingresar el titular con el tag original, el contador leído será menor al registrado detectándose la clonación. Ante este evento, el UID se bloquea y se notifica a los usuarios finales.

### 7.3. Protección de los datos del sistema

La otra forma de vulnerar la seguridad del sistema es mediante el acceso a este en cualquiera de sus tramos. A continuación se describen las consideraciones de seguridad de cada uno.
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

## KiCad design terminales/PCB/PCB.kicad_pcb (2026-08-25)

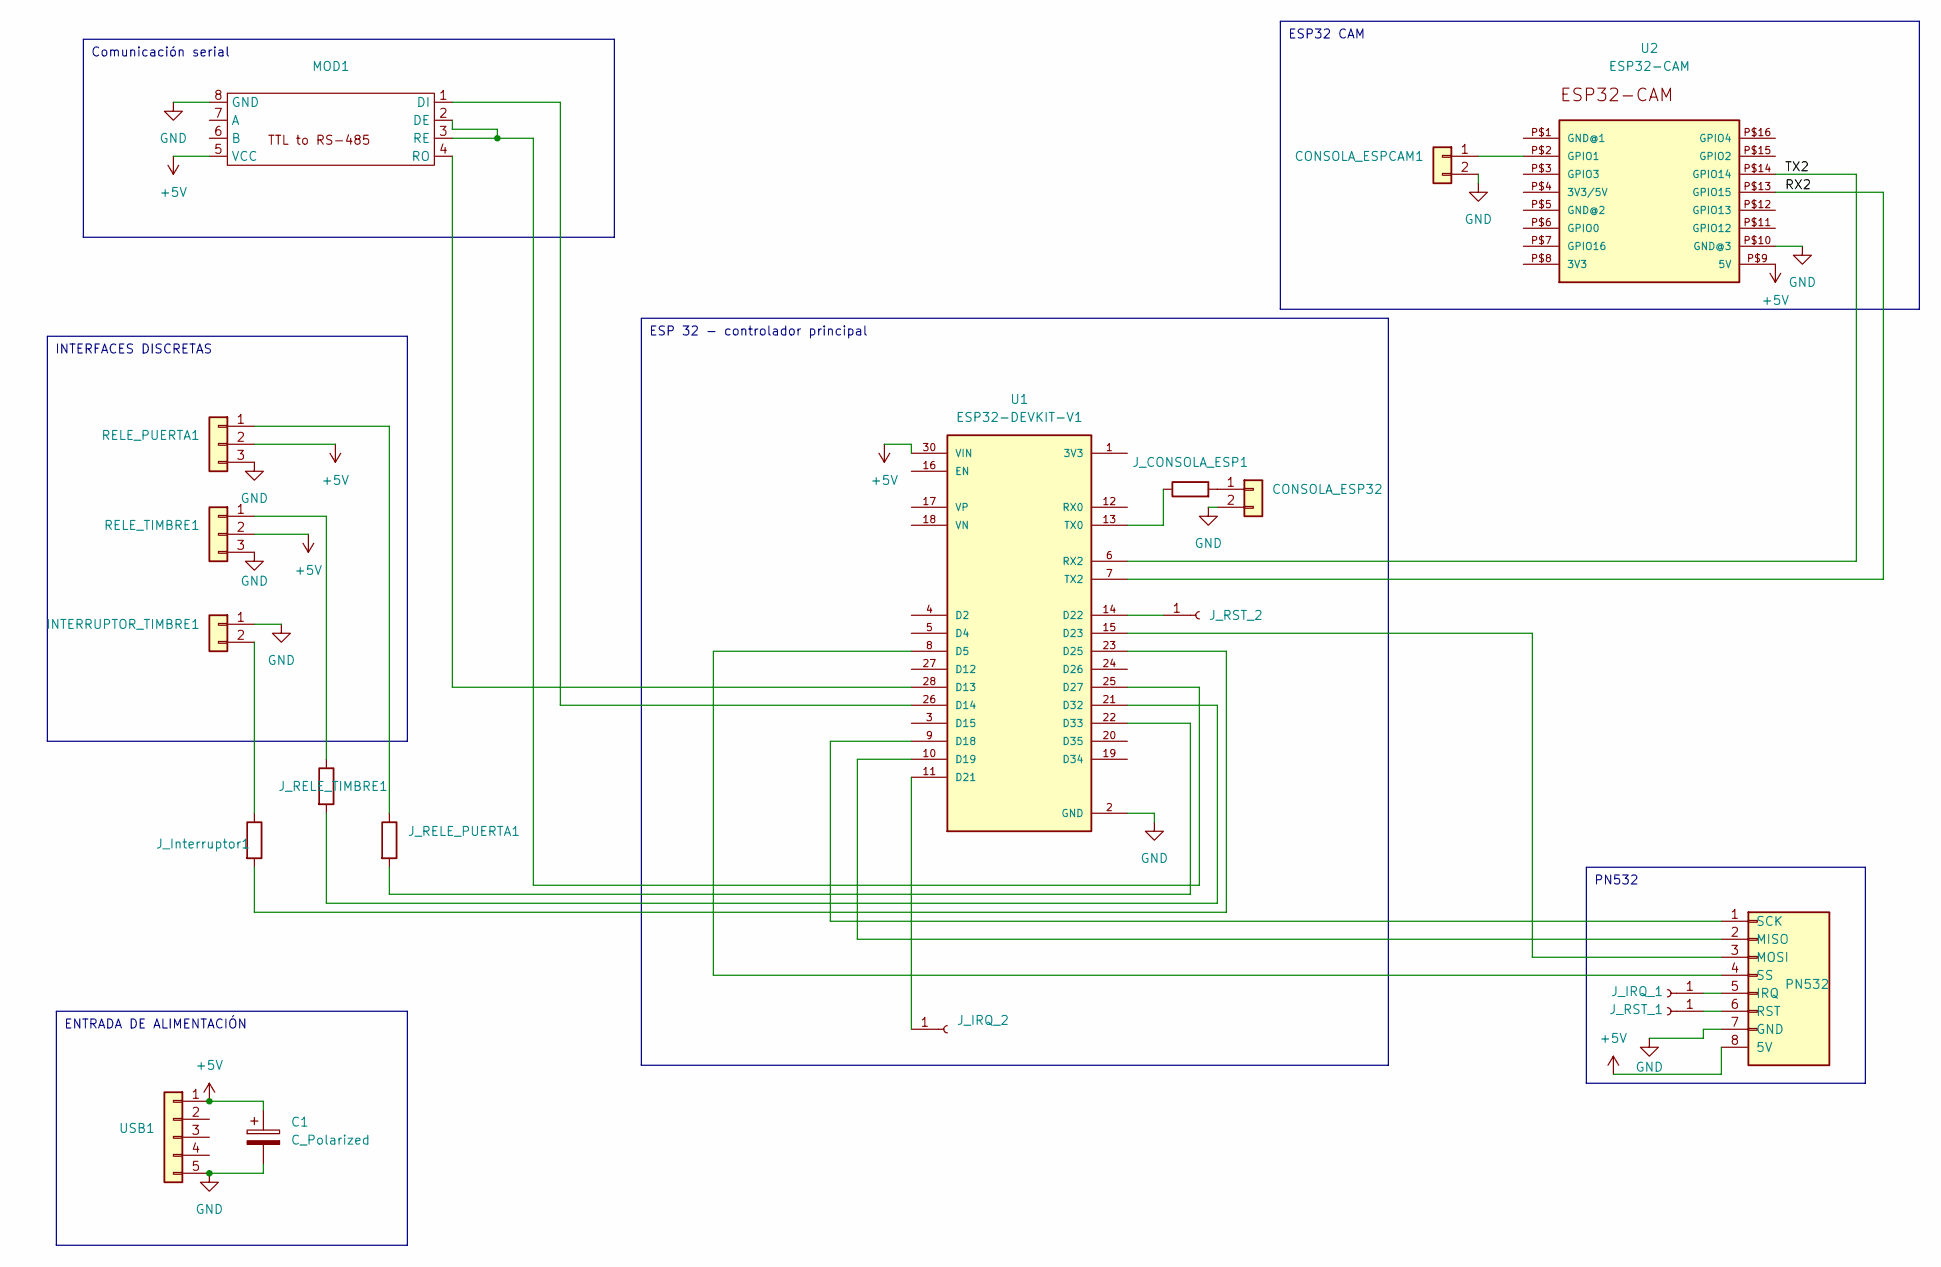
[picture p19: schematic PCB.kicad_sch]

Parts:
C1: C_Polarized; CP_Radial_D10.0mm_P2.50mm
CONSOLA_ESP32: Conn_01x02; PinHeader_1x02_P2.54mm_Vertical
CONSOLA_ESPCAM1: Conn_01x02; PinHeader_1x02_P2.54mm_Vertical
INTERRUPTOR_TIMBRE1: Conn_01x02; TerminalBlock_Phoenix_MKDS-1,5-2_1x02_P5.00mm_Horizontal
J_CONSOLA_ESP1: 0; R_Axial_DIN0207_L6.3mm_D2.5mm_P5.08mm_Vertical
J_IRQ_1, J_IRQ_2: Conn_01x01_Socket; PinSocket_1x01_P2.54mm_Vertical
J_Interruptor1: 0; R_Axial_DIN0207_L6.3mm_D2.5mm_P5.08mm_Vertical
J_RELE_PUERTA1: 0; R_Axial_DIN0207_L6.3mm_D2.5mm_P5.08mm_Vertical
J_RELE_TIMBRE1: 0; R_Axial_DIN0207_L6.3mm_D2.5mm_P5.08mm_Vertical
J_RST_1, J_RST_2: Conn_01x01_Socket; PinSocket_1x01_P2.54mm_Vertical
MOD1: MAX485
PN532: PN532-Adafruit; PinHeader_1x08_P2.54mm_Vertical
RELE_PUERTA1: Conn_01x03; PinSocket_1x03_P2.54mm_Vertical
RELE_TIMBRE1: Conn_01x03; PinSocket_1x03_P2.54mm_Vertical
U1: ESP32-DEVKIT-V1; MODULE_ESP32_DEVKIT_V1; PARTREV N/A
U2: ESP32-CAM
USB1: Conn_01x05; PinSocket_1x05_P2.54mm_Vertical

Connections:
+5V: C1.1, MOD1.5 (VCC), PN532.8 (5V), RELE_PUERTA1.2, RELE_TIMBRE1.2, U1.30 (VIN), U2.P$9 (5V), USB1.1
/RX2: U1.7 (TX2), U2.P$13 (GPIO15)
/TX2: U1.6 (RX2), U2.P$14 (GPIO14)
GND: C1.2, CONSOLA_ESP32.2, CONSOLA_ESPCAM1.2, INTERRUPTOR_TIMBRE1.1, MOD1.8 (GND), PN532.7 (GND), RELE_PUERTA1.3, RELE_TIMBRE1.3, U1.2 (GND), U1.29 (GND), U2.P$10 (GND@3), USB1.5
unnamed: CONSOLA_ESP32.1, J_CONSOLA_ESP1.2
unnamed: CONSOLA_ESPCAM1.1, U2.P$2 (GPIO1)
unnamed: INTERRUPTOR_TIMBRE1.2, J_Interruptor1.1
unnamed: J_IRQ_1.1, PN532.5 (IRQ)
unnamed: J_IRQ_2.1, U1.11 (D21)
unnamed: J_RST_1.1, PN532.6 (RST)
unnamed: J_RST_2.1, U1.14 (D22)
unnamed: MOD1.2 (DE), MOD1.3 (RE), U1.25 (D27)
unnamed: MOD1.1 (DI), U1.26 (D14)
unnamed: MOD1.4 (RO), U1.28 (D13)
unnamed: PN532.2 (MISO), U1.10 (D19)
unnamed: PN532.3 (MOSI), U1.15 (D23)
unnamed: PN532.1 (SCK), U1.9 (D18)
unnamed: PN532.4 (SS), U1.8 (D5)
unnamed: J_RELE_PUERTA1.1, RELE_PUERTA1.1
unnamed: J_RELE_TIMBRE1.1, RELE_TIMBRE1.1
unnamed: J_Interruptor1.2, U1.23 (D25)
unnamed: J_RELE_TIMBRE1.2, U1.21 (D32)
unnamed: J_RELE_PUERTA1.2, U1.22 (D33)
unnamed: J_CONSOLA_ESP1.1, U1.13 (TX0)

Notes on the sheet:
PN532
ENTRADA DE ALIMENTACIÓN
Comunicación serial
INTERFACES DISCRETAS
ESP 32 - controlador principal
ESP32 CAM

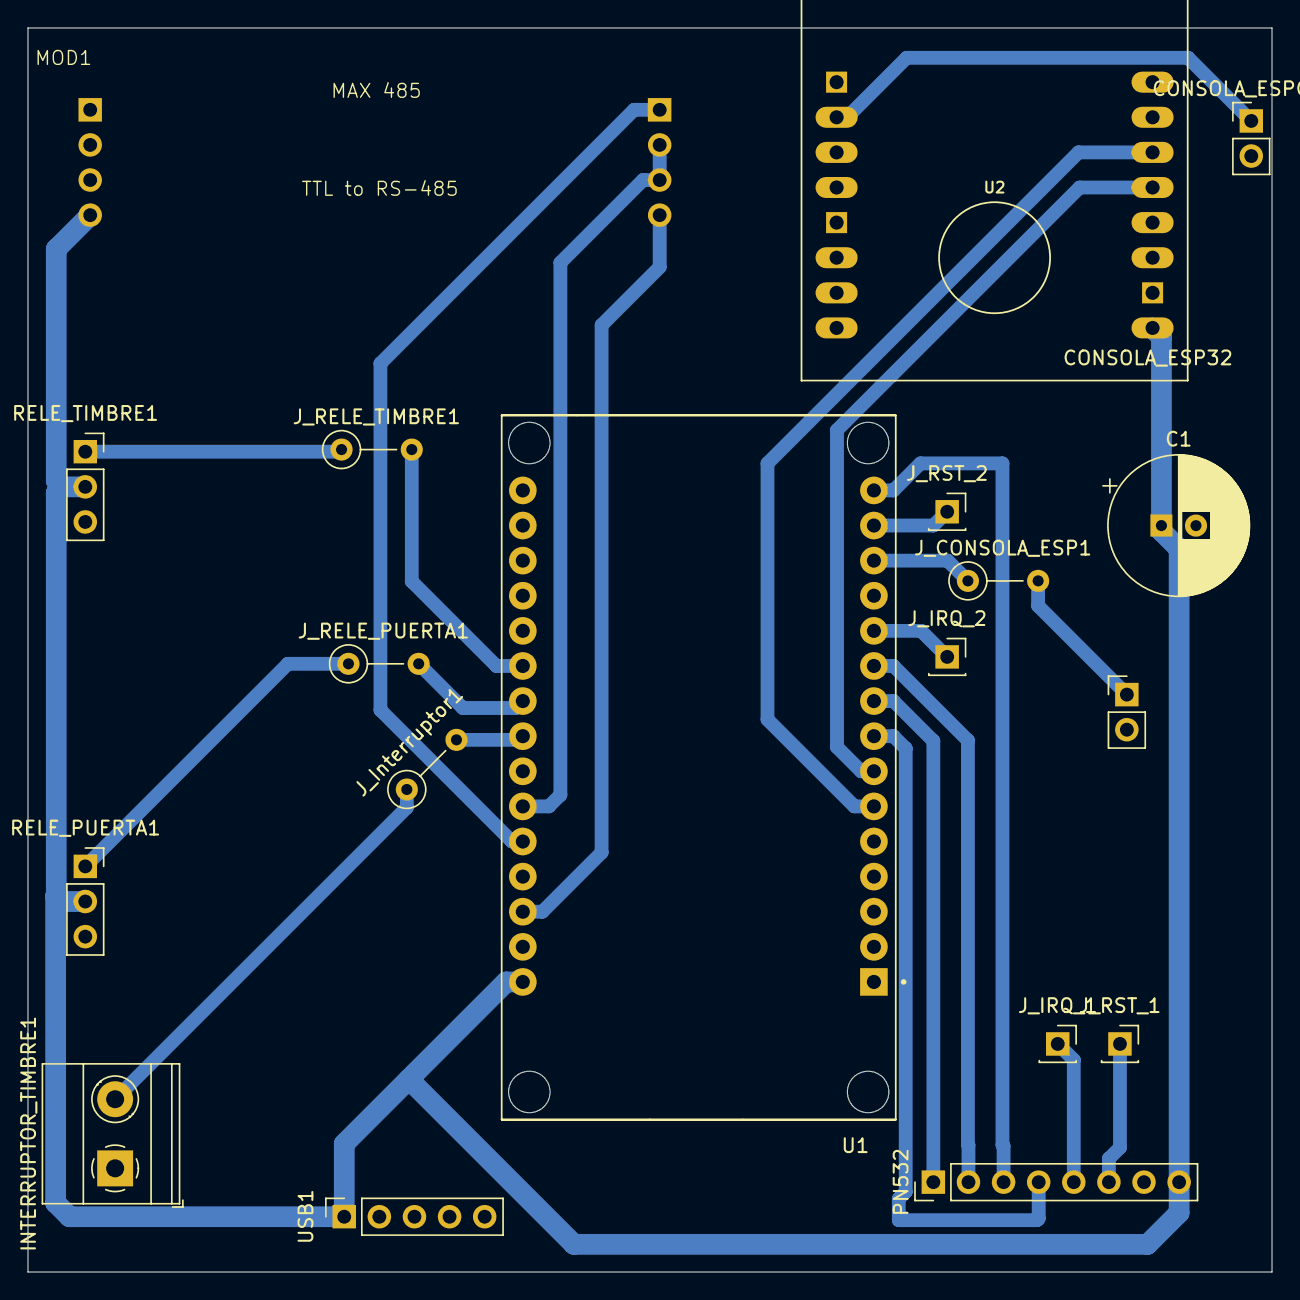
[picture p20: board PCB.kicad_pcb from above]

Board: 2 copper layers, 90.0 x 90.0 mm, 19 parts (0 on the bottom side), 24 nets.

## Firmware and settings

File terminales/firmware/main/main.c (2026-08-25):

#include <stdio.h>
#include "freertos/FreeRTOS.h"
#include "freertos/task.h"

#include "driver/uart.h"
#include "driver/gpio.h"

#include "config.h"
#include "app_uart.h"
#include "protocol.h"
#include "DIO.h"

#include "app_wifi.h"
#include "app_NFC.h"
#include "camara.h"
#include "esp_log.h"
#include "driver/i2c_master.h"
#include "esp_err.h"
#include "nvs_flash.h"
#include "uart_cam.h"

    //Medicion de tiempos de respuesta
    int64_t ti =0;
    int64_t tf =0;


void reset_task(void *pvParameters) {
    
    SemaphoreHandle_t cmd_sem = protocol_get_ctrl_sem(CMD_RESET);
    if (cmd_sem == NULL) {
        ESP_LOGE("RESET", "No se pudo obtener el semáforo de reset");
        esp_restart();
    }

    while(1){
        if (xSemaphoreTake(cmd_sem, portMAX_DELAY) == pdTRUE) {
            esp_restart();
        }                               
    }
}

void app_main(void){ 

    //Inicializar el protocolo y la comunicación serial:
    protocol_params_t parametros;
    parametros.ctrl_cmds =10;
    parametros.st_cmds =10;
    parametros.masterid= MASTER_ID;
    parametros.nodoid = NODO_ID_DEFAULT;

    parametros.dispatcher_priority = 8;
    parametros.buffer_getter = uart_get_rx_streambuffer;
    parametros.dispatcher_stack =4096;

    parametros.sender = app_uart_send;
    parametros.parser_priority = 7;
    parametros.parser_stack = 4096;
    
    uart_init();
    xTaskCreate(uart_rx_task,"RX_TASK",4096,NULL,10,NULL);
    protocol_init(&parametros);


    cam_uart_init();
    xTaskCreate(cam_uart_rx_task,"WIFI",4096,NULL,9,NULL);
    //Inicializar las tareas


    xTaskCreate(app_wifi_com_task,"WIFI",4096,NULL,3,NULL);
    nfc_init();
    dio_init();

    
    xTaskCreate(camara_task,"CAM",4096,NULL,3,NULL);

    xTaskCreate(reset_task,"RST",512,NULL,20,NULL);
    composer(CMD_READY,0,NULL,NULL);

}
   

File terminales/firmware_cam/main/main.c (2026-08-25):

#include <stdio.h>
#include "freertos/FreeRTOS.h"
#include "freertos/task.h"

#include "driver/uart.h"
#include "driver/gpio.h"
#include "nvs_flash.h"
#include "config.h"


#include "app_wifi.h"
#include "camara.h"
#include "esp_log.h"

#include "esp_err.h"

#include "uart_cam.h"



void app_main(void){ 
    
    
    cam_uart_init();
    xTaskCreate(cam_uart_rx_task,"WIFI",4096,NULL,3,NULL);

    esp_err_t ret = nvs_flash_init();
    if (ret == ESP_ERR_NVS_NO_FREE_PAGES || ret == ESP_ERR_NVS_NEW_VERSION_FOUND) {
        // Si la memoria está corrupta o cambió el mapa de particiones, la borramos y reinstanciamos
        ESP_ERROR_CHECK(nvs_flash_erase());
        ret = nvs_flash_init();
    }
    ESP_ERROR_CHECK(ret);

    
    vTaskDelay(pdMS_TO_TICKS(2000));

    xTaskCreate(app_wifi_com_task,"WIFI",4096,NULL,3,NULL);


    
    xTaskCreate(camara_task,"CAM",8192,NULL,3,NULL);
    gpio_reset_pin(FLASH);
    gpio_set_direction(FLASH, GPIO_MODE_OUTPUT);
    ESP_LOGW("INIT","COMENZANDO FLASH");
    gpio_set_level(FLASH, 1);
    vTaskDelay(pdMS_TO_TICKS(2000));
    gpio_set_level(FLASH, 0);

    //Forzar intento de conexión al resetar
    vTaskDelay(pdMS_TO_TICKS(400)); //dejamos descansar la alimentación
    uint8_t cmd_auto_connect[2] = {UART_CAM_WFON_CMD, 0x00};//El comandito
    MessageBufferHandle_t wf_buff = get_msjbuff_wf();//recuperamos el biuffer
    xMessageBufferSend(wf_buff, cmd_auto_connect, sizeof(cmd_auto_connect), portMAX_DELAY);//mandamos a conectar
}
   

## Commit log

2026-08-25 Archivos del servidor
    El contenido de este directorio, aplicando las modificaciones y configuraciones correpsondientes, permite implementar el servidor del sistema
    [accesos_autorizados.csv]
2026-08-25 Archivos Firmware terminales
    Se suben las carpetas de proyecto ESP-IDF con el firmware para ESP32 y ESP32 CAM correspondiente a los microcontroladores presentes en el terminal
2026-08-25 Archivos de PCB
    Subda de archivos de KiCAD para construcción de PCB de prototipo
    [PCB.kicad_pcb, PCB.kicad_sch]
